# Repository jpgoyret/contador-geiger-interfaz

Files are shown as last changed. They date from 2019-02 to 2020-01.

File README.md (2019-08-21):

# Interfaz de manejo y visualización de los datos de un contador Geiger-Müller en microcontrolador de 8 bits

## Descripcion:
Dispositivo para controlar y recibir información de un detector de partículas radioactivas. Este informa la cantidad de partículas que han sido recibidas en un intervalo de tiempo deseado y, en particular, comunica cuando se ha superado un umbral de radiación establecido por el usuario.

El primer prototipo funcional de este proyecto fue realizado en el marco de la materia "6609/8607 Laboratorio de Microcontroladores" en la Facultad de Ingeniería de la Universidad de Buenos Aires (FIUBA).

La intrerfaz fue desarrollada sobre un microcontrolador de 8 bits Atmega328p (integrado en un Arduino) y programada en Assembly.

## Navegación del repositorio

En el archivo [Documentacion_Contador_Geiger](Documentacion_Contador_Geiger.pdf) se podrá encontrar la documentación propia de la interfaz incluyendo: breve descripción del desarrollo, diagramas de flujo y de bloques, componentes de la interfaz, conexiones, entre otros.

En [Mediciones_Contador_Geiger](Mediciones_Contador_Geiger.pdf) se incluyen las mediciones realizadas sobre el contador Geiger por medio de la interfaz de manejo y visualización de datos. Para dichas pruebas se empleó una fuente elevadora de tensión elaborada por Ing. Ricardo Arias.

#### Carpetas:

- Codigo: incluye el código fuente del programa que irá embebido en el microcontrolador Atmega328p. Dicho código puede ser copiado y pegado dentro de la carpeta de un proyecto de Atmel Studio para poder ser modificado.
- diseño_caja_contador_geiger: contiene los archivos 3D del diseño de una caja que contenga a la fuente elevadora de tensión armada en una placa de 10cmx10cm.
- esquematicos: contiene los esquemáticos del PCB del shield del Arduino y del teclado.

## Integrantes del equipo:
- Nuñez Frau, Federico
- Vidal, Gabriel
- Goyret, Juan Pablo

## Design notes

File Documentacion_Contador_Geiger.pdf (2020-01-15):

## Interfaz de manejo y visualización de los datos de un contador Geiger-Müller

## Documentación

Facultad de Ingeniería, Universidad de Buenos Aires

15 de enero de 2020

## Autores:

Nuñez Frau, Federico | 98211 | fedenunez32@gmail.com
Vidal, Gabriel | 97772 | vidalgabriel93@gmail.com
Goyret, Juan Pablo | 99081 | juanpablogoyret@gmail.com

Índice

1. Descripción | 2
2. Diagrama de bloques | 3
3. Diagramas de flujo | 4
4. Esquemático | 5
5. Configuración de la interfaz | 6
6. Comunicación | 7
7. Firmware | 11

### 1. Descripción

El dispositivo consiste en una interfaz de manejo y visualización de los datos de un contador Geiger-Müller, el cual es un circuito analógico generador de pulsos de tensión a partir de las partículas radioactivas que son recibidas en un tubo Geiger- Müller. Este último es un tubo de vidrio entre cuyos bornes se debe crear una tensión en torno a los cientos de volts y que, al recibir una partícula radioactiva, genera un pulso de corriente entre su ánodo y su cátodo, el cual es luego transformado a un pulso de tensión por un circuito secundario. Dado que las partículas arriban al tubo en instantes de tiempo aleatorios, los pulsos también se generan de este modo.
Estos pulsos de tensión son contados por un microcontrolador Atmega328p embebido en una placa Arduino, el cual realiza la tarea de determinar cuantos de estos han sido detectados en una unidad de tiempo dada, al igual que registrar los tiempos de llegada de cada pulso, para luego informarlo al usuario. Como se observa en el diagrama de bloques de la Figura 1, los pulsos de tensión son comunicados al microcontrolador a través de opto-acopladores rápidos, para aislar eléctricamente al circuito analógico del digital (además, ambos se encuentran en placas separadas). Se cuenta además con una salida del microcontrolador opto-acoplada para encender la fuente de alta tensión que excita el tubo Geiger-Müller. El microcontrolador informa la cantidad de pulsos de tensión recibidos por unidad de tiempo al usuario por medio de un panel LCD 2x16; así como también a una PC por medio de USB, empleando el sistema de comunicación UART y utilizando el protocolo SCPI (Standard Commands for Programmable Instruments)

1
. Este último medio es también utilizado para enviar los tiempos de llegada de cada pulso, permitiéndole al usuario realizar, por ejemplo (pero no contemplados en este trabajo), análisis estadísticos de la radiación recibida. Esta conexión permite, además, dar comienzo o detener mediciones a través de la PC.
Además, el sistema cuenta con un teclado conformado por 6 pulsadores: flechas en las 4 direcciones, un botón de cancelar y uno de aceptar; con las siguientes funciones:

Controlar el largo del intervalo de tiempo en el cual se cuentan los pulsos antes de informar un valor al usuario o "ventana de tiempo". Este valor se modifica mediante un menú de configuración visible en el display LCD.

Dar comienzo o detener las mediciones.

Configurar un umbral de pulsos recibidos por unidad de tiempo, el cual, de ser superado, implica el encendido de un LED rojo (de no ser superado el umbral se mantiene encendido un LED verde) y/o la activación de una alarma.

El microcontrolador utilizado se encuentra embebido en una placa Arduino UNO Rev3. Sobre este se acopla mediante pines largos una placa aparte (utilizando el formato poncho o shield), el cual contiene el buzzer para la alarma sonora y conectores para tres cables dirigidos a 3 placas extra. Una de ellas posee el display LCD; otra el teclado y los LEDs; y la última la fuente elevadora de tensión del contador. Por otro lado, la otra placa cuenta con la fuente de alta tensión encargada de alimentar al tubo del contador, y comunicar los pulsos al Atmega328.
El circuito analógico será alimentado mediante un transformador de 220V a 6V, contando el bloque digital con una alimentación independiente.
En las Figuras 2 y 3 se muestran los diagramas de flujo del menú de control y del sistema contador de pulsos respectivamente.

1
“SCPI 1999.0".Internet: http://www.ivifoundation.org/docs/scpi-99.pdf [Mayo, 1999]

### 2. Diagrama de bloques

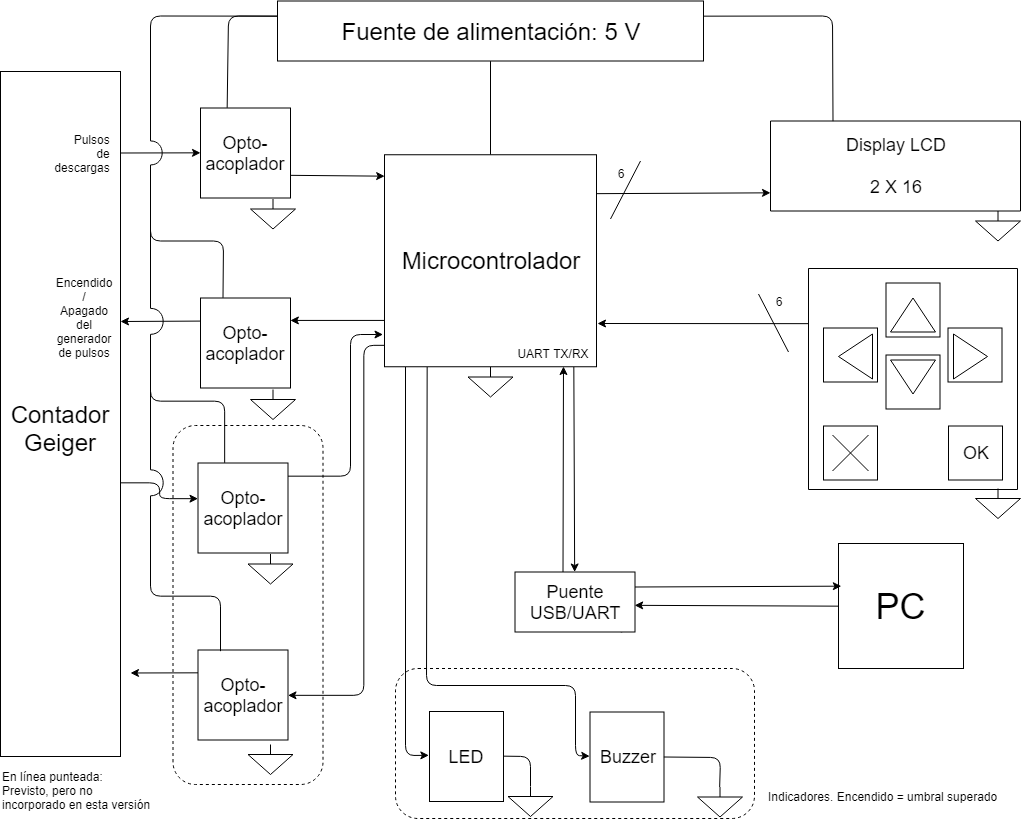
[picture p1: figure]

Figura 1: Diagrama de bloques.

### 3. Diagramas de flujo

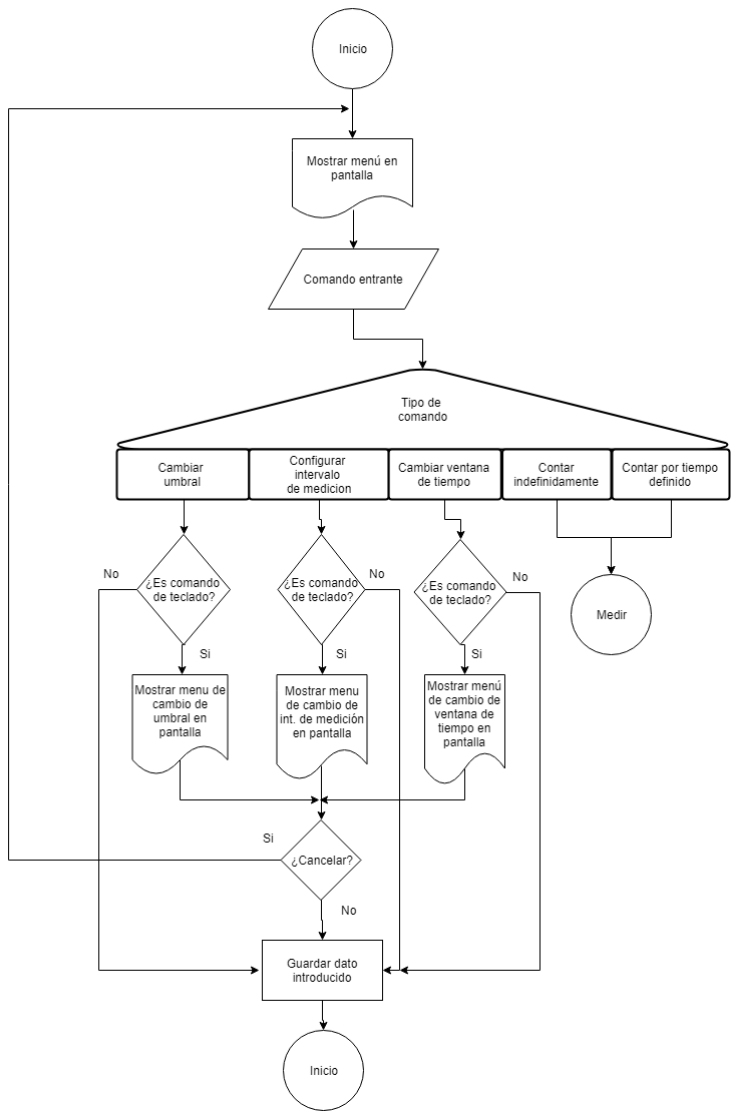
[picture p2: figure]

Figura 2: Diagrama de flujo del menú de control del contador.

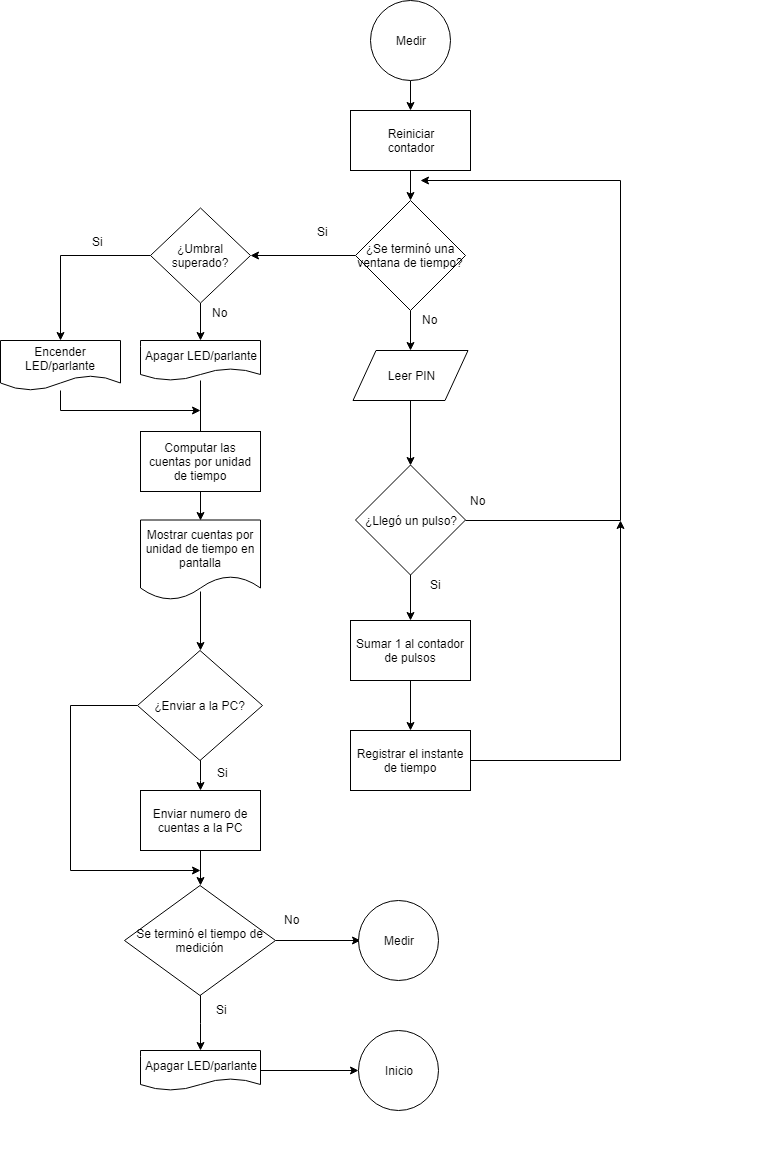
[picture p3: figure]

Figura 3: Diagrama de flujo del algoritmo de medición.

### 4. Esquemático

Los esquemáticos se podrán ver accediendo a los distintos proyectos en Kicad dentro del repositorio del proyecto en la carpeta proyectos_esquematico_kicad. A continuación se listan los nombres de cada proyecto con el correspondiente componente que representan de todo el dispositivo:

Placa_lcd_cont_geiger: shield de Arduino del cual parten los conectores que se dirigen a la placa del teclado y a la placa que posee la fuente elevadora.

esquematico_lcd: placa adaptadora que solamente cuenta con un puerto IDC para recibir las señales del Arduino y dirigirlas a los pines de la pantalla LCD.

teclado_contador_geiger: placa con el teclado para comandar el dispositivo y los LEDs rojo y verde indicadores.

### 4.1. Pines del microcontrolador/Arduino y su función

A continuación, en el Cuadro 1 se especifica la funcionalidad de cada pin del microcontrolador Atmega328p para el contador Geiger, junto con su correlación con las salidas del Arduino UNO R3.

Pin Arduino UNO R3 | Pin Atmega328p | Funcionalidad
Digital 0 | PD0 | Comunicación UART - RX
Digital 1 | PD1 | Comunicación UART - TX
Digital 2 | PD2 | Pantalla LCD: RS
Digital 3 | PD3 | Pantalla LCD: E
Digital 4 | PD4 | Pantalla LCD: datos
Digital 5 | PD5 | Pantalla LCD: datos
Digital 6 | PD6 | Pantalla LCD: datos
Digital 7 | PD7 | Pantalla LCD: datos
Digital 8 | PB0/ICP1 | Recepción de pulsos del tubo
Digital 12 | PB4 | Habilitación de la fuente de alta tensión
Analógico 0 (A0) | PC0 | Teclados
Analógico 1 (A2) | PC1 | Encendido de buzzer indicador
Analógico 4 (A4) | PC4 | Encendido del LED indicador verde
Analógico 5 (A5) | PC5 | Encendido del LED indicador rojo

Cuadro 1: Listado de los pines del Arduino UNO R3/Atmega328p con su respectiva funcionalidad para el contador Geiger.

### 5. Configuración de la interfaz

### 5.1. Parámetros configurables

La interfaz de control y gestión contempla la posibilidad de configurar los siguiente parámetros de medición:

Cantidad de ventanas de tiempo a medir: entre 1 y 99999.

Duración de las ventanas de tiempo a medir: 1ms, 10ms, 100ms o 1s.

Umbral por encima del cual se activa una señal luminosa o sonora: entre 0 y 99999.

Activación o desactivación de la señal sonora.

Activación o desactivación de la fuente de alta tensión del tubo del contador Geiger-Müller.

Activación del modo para retornar los tiempos de llegada de las partículas radioactivas al tubo.

A su vez, también es posible guardar las configuración del dispositivo en memoria EEPROM (mediante el comando *SAV por UART). De hacerselo, al resetearse este tomará automáticamente la configuración guardada.

### 5.2. Configuración por default

Los siguientes valores son los correspondientes a la configuración por default del dispositivo.

Tiempo de la ventana: 1s.

Número de ventanas: 10.

Umbral de la señal luminosa/sonora: 1.

Estado de la fuente: desactivada.

Envío de tiempo de llegada de cada pulso: desactivado.

El dispositivo puede ser retornado a su configuración por default ejecutando el comando *RST.

### 6. Comunicación

### 6.1. Comunicación con PC / serie

La comunicación serie por USB con la PC se realiza empleado la USART del Atmega328p en modo UART. Para la conexión física se utiliza el harware del propio Arduino como adaptador de serie a USB. La comunicación por UART se encuentra configurada del siguiente modo:

Baud rate: 76800 (se genera un 2 % de error).

Tamaño de la palabra: 8 bits.

Bit de paridad: no.

Cántidad bits de stop: 1

Las cadenas de texto con comandos SCPI a enviar deben terminar con el caracter de retorno de carro ˚. Por ejemplo, para comenzar una lectura enviar: READ?˚. De otro modo, el dispositivo nunca identificará que el mensaje enviado ha terminado y lanzará un error por timeout, devolviendo por consola el código -365.
Para comunicarse desde una PC puede utilizarse, por ejemplo, el programa PuTTY (al momento de realizar este trabajo, su última versión es la 0.7) disponible para Windows y Unix. Además de configurar el baud rate, el tamaño de palabra, el bit de paridad y el número de bits de stop como ya fue indicado, se debe configurar la pestaña "terminal"del modo en el que se muestra en la Figura 4

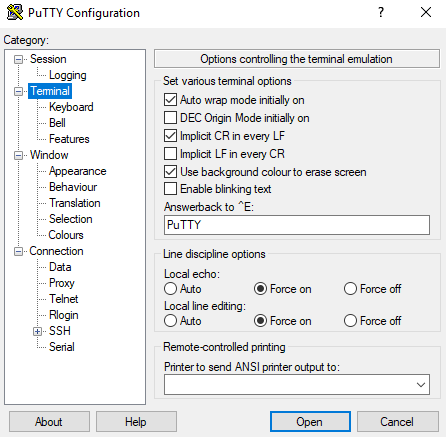
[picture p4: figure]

Figura 4: Configuración de la pestaña terminal de PuTTY.

### 6.2. Protocolo SCPI

Como ya se indicó, la comunicación serie se realiza utilizando el protocolo SCPI. Los comandos implementados son los que se muestras en el Cuadro 2.

Comando | Parámetro | Acción
*IDN? | N/C | Devolver un mensaje de identificación del dispositivo
*RST | N/C | Devolver la configuración del dispositivo a sus valores por default (ver 5.2)
READ? | N/C | Iniciar una medición utilizando la configuración actual del dispositivo
ABORt | N/C | Detener una medición
CONFigure? | N/C | Devolver la configuración de todo el dispositivo
CONFigure:WINDow <N> | Tamaño de la ventana. Valores posibles de N: 0 (1ms), 1 (10ms), 2 (100ms) y 3 (1s) | Configurar la duración de las ventanas de tiempo
CONFigure:WINDow? | N/C | Devolver el tamaño de la ventana de tiempo
CONFigure:COUNt <N> | Entre 1 y 99999 | Configurar la cantidad de ventanas a medir
CONFigure:COUNt 0 | N/C | Medir infinitas ventanas
CONFigure:COUNt? | N/C | Devolver el número de ventanas a medir
CONFigure:TRIGger <N> | Entre 0 y 99999 | Configurar el valor del umbral a partir del cual se enciende el LED o la alarma sonora (de encontrarse activada)
CONFigure:TRIGger? | N/C | Devolver el valor del umbral
CONFigure:DATA <BOOL> | 0 (desactivado) o 1 (activado) | Configurar el retorno de los tiempos de los pulsos que arribar al contador
CONFigure:DATA? | N/C | Devolver si el el retorno de los tiempos de los pulsos está activado o no
CONTrol:APOWer <BOOL> | 0 (desactivado) o 1 (activado) | Encender o apagar la fuente de alta tensión
CONTrol:APOWer? | N/C | Devolver si el tubo se encuentra recibiendo alta tensión o no
SYSTem:BEEPer:STATe <BOOL> | 0 (desactivado) o 1 (activado) | Encender o apagar la alarma sonora
SYSTem:BEEPer:STATe? | N/C | Devolver si la alarma sonora se encuentra activada
*SAV | N/C | Guardar la configuración del dispositivo en memoria EEPROM para retomarla cuando este se reinicie

Cuadro 2: Comandos SCPI implementados para comunicación serie. <N>es un parámetro representado por un número entero, mientras que <BOOL>uno representado por un booleano.

Varios comandos mostrados en el Cuadro 2 tienen una forma extendida y una forma reducida. La forma extendida comprende todos los caracteres del comando tal y como se lo muestra en la columna izquierda de la tabla. Por otro lado, la forma reducida se ve representada solamente por la letras en mayúscula y los símbolos como ": ²

¿". Tanto la forma reducida como la extendida son válidas. Por ejemplo, si se tiene el comando ÇONFigure:DATA?", su forma reducida sería ÇONF:DATA?". Del mismo modo, con CONFigure:WINDow <N>, su forma reducida es CONF:WIND <N>. En ambos casos ejemplo se obtendrá la misma respuesta tanto para el comando extendido como para el reducido.
A continuación se muestran algunos ejemplos. Recordar que a todos los comandos, tal y como son presentados en dichos ejemplos, se les debe agregar el caracter de retorno de carro (˚) de modos que sean correctamente interpretados por la interfaz.

### 6.2.1. Ejemplo 1

Suponiendo que se quisiera encender la alimentación de alta tensión del tubo del contador Geiger, se podría ejecutar el siguiente comando:

CONTrol:APOWer 1

O, en su forma, reducida:

CONT:APOW 1

Y también se podría enviar, por ejemplo:

CONT:APOWer 1

o bien,

CONTrol:APOW 1

En todos los casos, la fuente de alta tensión será encendida.

### 6.2.2. Ejemplo 2

Si se quisiera configurar la ventana de tiempo en 10ms y que el dispositivo mida 100 ventanas se podrían enviar los siguientes comandos:

CONF:WIND 2
CONF:COUN 100

### 6.2.3. Ejemplo 3

Si se quisiera saber el número de pulsos recibidos en la ventana de tiempo configurada tal que la señal luminosa o sonora se encienda (umbral superado), se podría ejecutar el siquiente comando:

CONF:TRIG?

Y el dispositivo devolverá el valor correspondiente

### 6.2.4. Códigos

La implementación del protocolo SCPI en la interfaz de gestión y control contempla algunos códigos de error o de información, que son los que se presentan en el Cuadro 3

Código | Significado
-100 | El comando recibido es erróneo
-365 | Timeout en la recepción de un comando. Se ha comenzado a recibir un comando pero su último caracter ha tardado demasiado tiempo en llegar.
-363 | Comando demasiado extenso (>60 caracteres). Overflow en el buffer de recepción de comandos
-284 | Dispositivo ocupado. No se puede recibir un comando en este momento

Cuadro 3: Códigos implementados del estándar SCPI.

### 7. Firmware

### 7.1. Máquinas de estado y eventos

El firmware consiste principalmente de 3 máquinas de estado, cada una asociada a funcionalidades distintas de la interfaz de control y gestión. Estas son:

Realización de las mediciones.

Recepción y envío de datos por UART.

Menú mostrado en la pantalla LCD del dispositivo.

Los estados de las primeras dos máquinas se encuentran almacenados en el registro ESTADO (R24), mientras que el de la tercera lo hace en ESTADOS_LCD (R22). Ambos son registros reservados que no pueden ser accedidos por ningún otro proceso.
Las máquinas cambian de estado o ejecutan acciones dependiendo de los eventos que ocurran en el microcontrolador, como la llegada de un caracter por UART o un pulso por el pin ICP1. Dichos estados se almacenan en el registro reservado EVENTO (R25), y en el registro en RAM EVENTO2. Este último fue creado debido a la falta de registros de acceso común disponibles para ser reservados a una tarea en específico.

### 7.2. Timers

La interfaz de control y gestión utiliza los tres timers disponibles en el microcontrolador Atmega328P. Sus funciones son:

Timer 0:

- Identificar un timeout (o exceso de tiempo) en la recepcion de una cadena de caracteres por UART. Se genera una interrupcion si ha transcurrido un cierto tiempo desde la llegada de un primer caracter sin que se haya recibido un caracter de fin de trama.
- Debouncer para detectar la pulsación de una tecla en el teclado mediante el comparador y el ADC.

Timer 1: guardar los instantes de tiempo de los pulsos capturados.

Timer 2: generar los delays del LCD.

### 7.3. Registros

En el Cuadro 4 pueden verse los registros de uso común R0 a R31 catalogados según su uso. Si se encuentran reservados para alguna tarea en específico (no pueden ser utilizados en ninguna otra función que no sean aquellas relacionadas con el proceso para el cual se encuentran justamente reservados), entonces se aclara su motivo.

Registro | Reservado | Uso | Definición
R0 | Si | Multiplicaciones | N/C
R1 | Si | Multiplicaciones | N/C
R2 | Si | Contador del timer 0 | CONT_TIMER0_LOW
R3 | Si | Contador del timer 0 | CONT_TIMER0_HIGH
R4 | No | Uso general | N/C
R5 | No | Uso general | N/C
R6 | No | Uso general | N/C
R7 | No | Uso general | N/C
R8 | Si | Puntero al LSB del buffer de transmisión de UART | PTR_TX_L
R9 | Si | Puntero al MSB del buffer de transmisión de UART | PTR_TX_H
R10 | Si | Puntero al LSB del buffer de recepción de UART | PTR_RX_L
R11 | Si | Puntero al MSB del buffer de recepción de UART | PTR_RX_H
R12 | Si | Cantidad de caracteres almacenados en el buffer de transmisión de datos de UART | BYTES_TRANSMITIR
R13 | Si | Cantidad de caracteres almacenados en el buffer de recepción de datos de UART | BYTES_RECIBIDOS
R14 | No | Uso general | N/C
R15 | Si | Multiplicador para extender el tamaño de la ventana de tiempo | MUL_DE_VENTANA
R16 | No | Uso general | N/C
R17 | No | Uso general | N/C
R18 | No | Uso general | N/C
R19 | No | Uso general | N/C
R20 | No | Uso general | N/C
R21 | No | Uso general | N/C
R22 | Si | Estados de la máquina de estados del LCD | ESTADOS_LCD
R23 | Si | Lleva la cuenta de la cantidad de pulsos medidos | CONTADOR_DE_PULSOS
R24 | Si | Almacenamiento de los estados de las máquinas de estado de la comunicación serie y del sistema de recepción de los pulsos | ESTADO
R25 | | Almacenamiento de eventos que alteran los estados de las máquinas de estado | EVENTO
R26 | Si | Puntero X | N/C
R27 | Si | Puntero X | N/C
R28 | Si | Puntero Y | N/C
R29 | Si | Puntero Y | N/C
R30 | Si | Puntero Z | N/C
R31 | Si | Puntero Z | N/C

Cuadro 4: Comandos SCPI implementados para comunicación serie. <N>es un parámetro representado por un número entero, mientras que <BOOL>uno representado por un booleano. En la última columna se aclara la definición del registro en el código si es que se lo ha redeclarado con ".def".

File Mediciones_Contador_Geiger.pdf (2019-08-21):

## Interfaz de manejo y visualización de los datos de un contador Geiger-Müller

## Mediciones

Facultad de Ingeniería, Universidad de Buenos Aires

## Autores:

Nuñez Frau, Federico | 98211 | fedenunez32@gmail.com
Vidal, Gabriel | 97772 | vidalgabriel93@gmail.com
Goyret, Juan Pablo | 99081 | juanpablogoyret@gmail.com

Índice

1. Diciembre 2018 | 2
2. Febrero 2019 | 2
2.2. Datos reportados por el contador Geiger en la consola serie del Atmel Studio 7 para las

### 1. Diciembre 2018

A continuación, en la Tabla 1 se muestran los resultados reportados por el contador por UART para distintas mediciones con el tubo colocado en la pared de la fuente de radiación. Se realizaron 12 mediciones de 10 segundos cada una. Cada dato se corresponde con la cantidad de pulsos detectados durante 1 segundo. Vale aclarar que estás mediciones fueron para un mismo tubo, que fue el tercero utilizado.
No se han incluido los resultados para mediciones con el tubo sin colocar en la pared de la fuente debido a que en ningún momento se detectaron pulsos para este caso.
Medición | t = 1 | t = 2 | t = 3 | t = 4 | t = 5 | t = 6 | t = 7 | t = 8 | t = 9 | t = 10
1ra | 00167 | 00177 | 00156 | 00170 | 00213 | 00096 | 00155 | 00208 | 00157 | 00106
2da | 00093 | 00146 | 00171 | 00155 | 00146 | 00075 | 00124 | 00075 | 00157 | 00093
3ra | 00135 | 00062 | 00081 | 00065 | 00151 | 00117 | 00149 | 00101 | 00118 | 00043
4ta | 00052 | 00077 | 00047 | 00039 | 00116 | 00080 | 00115 | 00127 | 00084 | 00073
5ta | 00084 | 00089 | 00082 | 00114 | 00103 | 00153 | 00077 | 00185 | 00111 | 00016
6ta | 00068 | 00106 | 00097 | 00098 | 00044 | 00093 | 00149 | 00121 | 00099 | 00176
7ta | 00105 | 00087 | 00117 | 00132 | 00117 | 00134 | 00056 | 00114 | 00127 | 00101
8va | 00106 | 00047 | 00135 | 00055 | 00069 | 00032 | 00043 | 00087 | 00055 | 00099
9na | 00254 | 00104 | 00084 | 00036 | 00078 | 00085 | 00107 | 00120 | 00082 | 00083
10ma | 00152 | 00243 | 00241 | 00023 | 00246 | 00188 | 00206 | 00037 | 00249 | 00206
11ra | 00200 | 00240 | 00186 | 00193 | 00047 | 00012 | 00226 | 00218 | 00228 | 00201
12da | 00176 | 00247 | 00197 | 00178 | 00250 | 00224 | 00209 | 00225 | 00170 | 00185

Cuadro 1: Cuentas por segundo obtenidas durante 10 segundos para 12 mediciones distintas con el tubo pegado a la pared de la fuente de radiación.

### 2. Febrero 2019

Fecha: 8/2/19

Tubo utilizado: SBM-20

Tensión aplicada en los bornes del tubo: 400V (la tensión de alimentación recomendada)

Resistencia en serie con el tubo: 1MOhm (integrada en la placa) + 5.6MOhm (fuera de placa; agregada al tubo) = 6.6 MOhm (la resistencia recomendada es 5MOhm).

Placa del tubo alimentada con una fuente de 12V DC.

Dispositivos utilizados:

Multímetro UNI-T UT33A.

Contador Geiger de mano Galert 500P.

Procedimiento: se realizaron mediciones para el contador Geiger de mano y el contador desarrollado en la materia. Para cada caso, las superficies receptoras de radiación de cada uno fueron apoyadas en la tapa de la cámara más cercana a la fuente de radiación (la parte trasera de dispositivo en el caso del Galert, y el tubo en el caso del contador desarrollado por cuenta propia). Se configuró al Galert para que midiera constantemente los pulsos por minuto detectados y cada 10 segundos se tomó una medición. Por otro lado, se programó al contador Geiger propio para medir ventanas de 1 segundo durante 10 segundos, y finalmente se anotó el promedio de pulsos por segundo recibidos al final de ese periodo de tiempo. Los procedimientos para ambos dispositivos fueron realizados con la fuente de radiación apuntando en el sentido de la tapa y sin hacerlo. Finalmente, se tomaron mediciones en vacío de ambos dispositivos, es decir, estando el tubo y el Galert apoyados sobre una mesa, alejados de la fuente de radiación.

### 2.1. Mediciones

### 2.1.1. Galert 500P

CPM: cuentas por minuto Con radiación: con la fuente apuntando en el sentido de la tapa

| Con radiación | Sin radiación | En vacío
Núm. de medición | CPM | CPM | CPM
1 | 5020 | 100 | 30
2 | 4620 | 200 | 90
3 | 4690 | 170 | 50
4 | 4500 | 200 | 20
5 | 4760 | 200 | 50
6 | 4330 | 250 | 40
7 | 4560 | 140 | 70
8 | 4310 | 140 | 70
9 | 4480 | 190 | 40
10 | 4710 | 220 | 50
11 | 4640 | 180 | 20
12 | 4410 | 140 | 40
13 | 4490 | 220 | 30
Media | 4578 | 181 | 46
Desviación estándar | 194 | 42 | 21

### 2.1.2. Contador Geiger propio

PCS: promedio de cuentas por segundo

| Con radiación | Sin radiación | En vacío
Núm. de medición | PCS | PCS | PCS
1 | 109 | 14 | 1
2 | 140 | 27 | 1
3 | 121 | 4 | 1
4 | 86 | 7 | 1
5 | 105 | 7 | 0
6 | 147 | 20 | 1
7 | 147 | 1 | 0
8 | 127 | 7 | 0
9 | 122 | 15 | 0
10 | 103 | 7 | 0
11 | 108 | 12 | 0
12 | 117 | 10 | 0
13 | 147 | 24 | 0
Media | 121 | 12 | 0.4
Desviación estándar | 19 | 8 | 0.5

Finalmente, para el caso en vacío, se realizaron mediciones con el contador propio usando una ventana de 100ms y realizando un promedio de los pulsos recibidos cada 1s (100 ventanas). En este caso, el promedio reportado fue 0 para todas las mediciones realizadas. Sin embargo, en algunas ventanas se pudo obtener una cantidad de pulsos detectados mayor a 0.

### 2.2. Datos reportados por el contador Geiger en la consola serie del Atmel Studio 7 para

las mediciones realizadas

Resultados del comando “CONF?”
Numero de ventanas:

00010
Duracion de la ventana:
1000
Umbral del trigger:
00020
Estado de la fuente: ON
Envio de tiempos de llegada de cada pulso: OFF Señal sonora: OFF
Bloqueo del teclado durante medicion: OFF

Mediciones sin fuente: cada línea representa la cantidad de pulsos recibidos por segundo. Cada medición de 10 segundos está separada por una línea “-800” (que indica la terminación de una operación en el estándar SCPI).

00032 00006 00000 00019 00000 00000 00011 00023 00033 00025 -800 00031 00032 00000 00095 00038 00034 00000 00036 00008 00000 -800 00000 00014 00000 00000 00000 00000 00000 00016 00010 00000 -800 00000 00000 00000 00020 00042 00000 00013 00000 00000 00000 -800 00000 00000 00025 00022 00000 00000 00007 00020 00000 00000 -800 00000 00000 00008 00041 00109 00013 00000 00000 00022 00012 -800 00006 00000 00000 00004 00000 00000 00000 00000 00000 00000 -800 00026 00014 00000 00000 00023 00000 00059 00024 00028 00000 -800 00000 00000 00042 00030 00000 00014 00000 00028 00043 00000 -800 00000 00000 00009 00000 00000 00000 00004 00042 00016 00007 -800 00000 00000 00019 00000 00004 00000 00032 00036 00030 00000 -800 00043 00000 00000 00000 00014 00000 00017 00000 00011 00024 -800 00051 00000 00000 00014 00042 00046 00024 00037 00000 00028 -800

Mediciones con fuente:

00027 00079 00143 00059 00020 00235 00167 00054 00158 00150 -800 00041 00249 00079 00223 00043 00192 00183 00182 00065 00149 -800 00208 00015 00215 00156 00031 00100 00228 00014 00034 00216 -800 00223 00164 00010 00002 00039 00165 00185 00006 00037 00129 -800 00096 00178 00018 00132 00010 00185 00045 00187 00200 00011 -800 00228 00170 00070 00195 00153 00193 00130 00037 00196 00107 -800 00170 00154 00194 00147 00022 00017 00104 00233 00204 00225 -800 00104 00075 00219 00012 00248 00062 00012 00133 00182 00225 -800 00222 00102 00046 00124 00010 00119 00015 00170 00253 00159 -800 00091 00106 00189 00117 00022 00227 00092 00043 00071 00078 -800 00183 00196 00170 00020 00123 00127 00002 00007 00138 00117 -800 00230 00036 00120 00002 00214 00190 00143 00143 00093 00005 -800 00226 00090 00235 00103 00100 00021 00170 00166 00244 00122 -800

Mediciones del video:
00010
Duracion de la ventana:
1000
Umbral del trigger:
00020
Estado de la fuente: ON
Envio de tiempos de llegada de cada pulso: OFF Señal sonora: OFF
Bloqueo del teclado durante medicion: OFF

00215 00216 00201 00149 00120 00219 00098 00241 00041 00009 -800 00068 00201 00173 00088 00203 00163 00012 00016 00151 00213 -800

Mediciones en vacío con ventana de 1s:
Numero de ventanas:
00010
Duracion de la ventana:
1000
Umbral del trigger:
00020

Estado de la fuente: ON
Envio de tiempos de llegada de cada pulso: OFF Señal sonora: OFF
Bloqueo del teclado durante medicion: OFF

00000 00000 00004 00000 00000 00000 00000 00000 00000 00007 -800 00000 00005 00000 00000 00000 00000 00007 00000 00000 00000 -800 00000 00010 00003 00000 00000 00000 00000 00000 00001 00000 -800 00000 00000 00000 00000 00000 00000 00000 00005 00007 00000 -800 00000 00000 00000 00000 00001 00000 00000 00000 00000 00000 -800 00000 00008 00000 00000 00000 00007 00000 00000 00000 00000 -800 00000 00000 00000 00000 00000 00000 00000 00000 00000 00000 -800 00000 00000 00000 00000 00000 00000 00000 00002 00000 00005 -800 00000 00002 00000 00000 00000 00000 00000 00000 00000 00000 -800 00000 00000 00000 00000 00000 00000 00000 00000 00000 00000 -800 00000 00000 00000 00000 00000 00000 00000 00006 00000 00000 -800 00000 00004 00000 00000 00000 00000 00000 00000 00000 00000 -800 00000 00005 00000 00000 00000 00000 00000 00000 00000 00000 -800

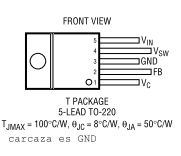
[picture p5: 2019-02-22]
proyectos_esquematico_kicad/esquematico_completo_primer_prototipo/LT1072.bmp

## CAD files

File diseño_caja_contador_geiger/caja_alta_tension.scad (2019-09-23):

// Carcasa para la placa de alta tensión

// Dimensiones que dan un resultado con sentido
//FootDia = 0.2;
//FootHole = 0.02;
//FootHeight = 0.2;
//Thick = 0.1;
//
//x = 3;
//y = 2;
//z = 1;
//dx = 0.4;
//dy = 0.4;
//dz = 0.4;
//rx = 0.1;
//ry = 1.8;
//rz = 0.1;

//DIMENSIONES DE LA PLACA
//9.4cm x 10.2 cm

//Dimensiones reales
//
FootDia = 8;    //Diametro del pie para la placa
FootHole = 0.1; //Agujero del tornillo
FootHeight = 14+2.6; //Altura del pie para la placa
Thick = 0.1;
Filet = 0.1;        //Constante que define el ancho de la base de los soportes para la placa

x = 114+2-5;
y = 115.3+2-4.44;
z = 70+2;
dx = 4+2;
dy = 4+2;
dz = 4+2;
rx = 1;
ry = 18;
rz = 1;

ex1 = 10;   //Espacio entre pared y placa del eje x en una dirección
ex2 = 3;    //Espacio entre pared y placa del eje x en la otra
ey1 = 3;    //Espacio entre pared y placa del eje y en una dirección
ey2 = 3.3;  //Espacio entre pared y placa del eje y en la otra

sx = 7;     //Espacio entre borde placa y pos. del agujero(+diametro)
sy = 5;    //Espacio entre el borde de la placa y la posicion del agujero (sumado el diametro)



// Posiciones de los soportes para la placa---------------
//pos_soportex1 = -x/2 + dx + ex2 + sx - FootDia/2;
//pos_soportex1 = -x/2 + dx - (FootDia+Filet)/2 + sx + ex2;
pos_soportex1 = -46.05+6-2.5;
pos_soportex3 = -46.05+6-2.5;
//pos_soportex2 = x/2 - dx - ex2 - sx + FootDia/2;
//pos_soportex2 = x/2 - dx + (FootDia+Filet)/2 - sx - ex1;
pos_soportex2 = 39.05+7-2.5;
pos_soportex4 = 39.05+7-2.5;
//pos_soportey1 = -y/2 + dy + ey1 + sy - FootDia/2;
//pos_soportey1 = -y/2 + dy+ ey1 + sy - (FootDia+Filet)/2;
pos_soportey1 = -48.7-5+2;
pos_soportey4 = -48.7-5+2;
//pos_soportey2 = y/2 - dy - ey2 - sy + FootDia/2;
//pos_soportey2 = y/2 - dy - ey2 - sy + (FootDia+Filet)/2;
pos_soportey2 = 48.4-6+2;
pos_soportey3 = 48.4-6+2;
pos_soportez = -(z-dz)/2;

//Agujero tubo---------------------------------------------------
//FUE CHEQUEADO
tubo_z = 16;
tubo_y = 8;
pos_tubo_x = x/2 - dx/4;
//pos_tubo_y = -y/2 + 45 - tubo_y/2;
pos_tubo_y = -y/2 -tubo_y/2 + 48;
//pos_tubo_z = -z/2 + 5 + 25 + tubo_z/2 + dz;
pos_tubo_z = -z/2 + tubo_z/2 + 30 - 10;
espesor_tubo = dx/2;

//Agujero Arduino-----------------------------------------------

arduino_x = 25;
arduino_z = 16;
pos_arduino_x = x/2 - arduino_x/2 - 33;
pos_arduino_y = -y/2 - dy/4;
pos_arduino_z = -z/2 + arduino_z/2 + 20 ;
espesor_arduino = dy/2;

//Agujero jack energía------------------------------------------

jack_x = 12;
jack_z = 14;
pos_jack_x = -x/2 + dx/4 + 33 + 4 - 2;
pos_jack_y = -y/2 - dy/4;
pos_jack_z = -z/2 + 23 + jack_z/2 - 4;
espesor_jack = dy/2;

//Ayuda para tornillo-------------------------------------------

tx = 10;
ty = 10;
tz = 35;
pos_tx = x/2-dx/2 - tx/2;
pos_ty = y/2-dy/2 - ty/2;
pos_tz = z/2 - tz/2;
d_tornillo = 2;

//Ayuda para tornillo tapa------------------------------------

//ttx = 70;
//tty = 12;
//ttz = 6;
ttx = 6;
tty = 30;
ttz = 30;
pos_ttx = -x/2 + ttx/2 + dx;
pos_tty = -y/2 + tty/2;
pos_ttz = -z/2 + ttz/2 + 30;

//Barras anti-flexibilidad--------------------------------------
off_z = 20;
off_x = 30;
bx = sqrt(pow(z-dz - off_z,2) + pow(y-dy,2)) - off_x;
by = dx/2;
bz = dx ;
pos_bx = x/2 - dx;
pos_by = y/2 - by/2 - dy/2;
pos_bz = z/2 - bz/4;
theta = atan((z-dz- off_z) / (y-dy));
alfa = atan((z-dz)/35);



module foot(FootDia,FootHole,FootHeight,Thick,Filet){
// Pie posa PCB
    // FootDia: diámetro de la parte donde se posa
    // FootHole: diámetro del agujero
    // FootHeigth: Altura del pie
    // Thick: cuanto se achica el pie para posar el PCB
    //Filet=2;  
    translate([0,0,0])
    difference(){
    
    difference(){
            //translate ([0,0,-Thick]){
                cylinder(d=FootDia+Filet,FootHeight-Thick, $fn=100);
                        //}
                    rotate_extrude($fn=100){
                            translate([(FootDia+Filet*2)/2,Filet,0]){
                                    minkowski(){
                                            square(10);
                                            circle(Filet, $fn=100);
                                        }
                                 }
                           }
                   }
            cylinder(d=FootHole,FootHeight+1, $fn=100);
               }          
}

module parte_inferior (x,y,z,dx,dy,dz,rx,ry,rz,tapa){
// Parte inferior de la placa de alta tensión
    
    // x: largo eje x
    // y: largo eje y
    // z: largo eje z
    // dx: grosor de la pared en el eje x
    // dy: grosor de la pared en el eje y
    // dz: grosor de la pared en el eje z
    // rx: largo del riel para encajar la tapa en el eje x
    // ry: largo del riel para encajar la tapa en el eje y
    // rz: largo del riel para encajar la tapa en el eje z
    //tapa: si vale 1 se genera la tapa, si vale 0, no
    
    difference(){
    
        cube([x,y,z],center=true);
        translate ([0,-dy/2,dz/2]) cube([x-dx,y,z],center=true);
//        translate ([x/2-dx/4,-(y-ry)/2,z/2-rz/2]) cube([rx,ry,rz],center=true);
//        translate ([-(x/2-dx/4),-(y-ry)/2,z/2-rz/2]) cube([rx,ry,rz],center=true);
//        translate ([-(x/2-dx/4),-(y-ry)/2,z/2-rz]) cube([rx*1.5,ry,rz],center=true);
//        translate ([x/2-dx/4,-(y-ry)/2,z/2-rz]) cube([rx*1.5,ry,rz],center=true);        
    }
}

module soporte_placa(x1,x2,x3,x4,y1,y2,y3,y4,z){
// Los cuatro pies donde se posa la placa

    translate ([x1,y1,z]) foot(FootDia,FootHole,FootHeight,Thick,Filet);
    translate ([x2,y2,z]) foot(FootDia,FootHole,FootHeight,Thick,Filet);
    translate ([x3,y3,z]) foot(FootDia,FootHole,FootHeight,Thick,Filet);
    translate ([x4,y4,z]) foot(FootDia,FootHole,FootHeight,Thick,Filet);  
    
    
}

//module tapa(x,y,z,dx,dy,dz,rx,ry,rz)
module tapa(x,y,z,dx,dy,dz)
{
    
    union(){
        translate ([0,-y/2-dy/4,0]) cube([x,dy/2,z],center=true);
        
        translate ([0,-dy/4,z/2+dz/4]) cube([x,y+dy/2,dz/2],center=true);
        
//        translate ([x/2-dx/4,-(y-ry)/2,z/2-rz]) cube([rx*1.5,ry,rz],center=true);
//        translate ([x/2-dx/4,-(y-ry)/2,z/2-rz/2]) cube([rx,ry,rz],center=true);
//        
//        translate ([-(x/2-dx/4),-(y-ry)/2,z/2-rz/2]) cube([rx,ry,rz],center=true);
//        translate ([-(x/2-dx/4),-(y-ry)/2,z/2-rz]) cube([rx*1.5,ry,rz],center=true);
        
        
        
    }
}

module agujero(dim_x,dim_y,dim_z,pos_x,pos_y,pos_z){
    
    translate ([pos_x,pos_y,pos_z]) cube([dim_x,dim_y,dim_z],center = true);    
}

module ayuda_para_tornillo(tx,ty,tz,pos_tx,pos_ty,pos_tz)
{
    translate([pos_tx,pos_ty,pos_tz]) cube([tx,ty,tz],center = true);
    
    translate([-pos_tx,pos_ty,pos_tz]) cube([tx,ty,tz],center = true);
    
    
    
//    difference(){
//        translate ([pos_tx,pos_ty,pos_tz]) cube([tx,ty,tz],center = true);
//        translate([pos_tx-(abs(pos_tx)/pos_tx)*tx/2,pos_ty-(abs(pos_tx)/pos_tx)*ty/2,pos_tz-tz/2]) rotate (a = [(abs(pos_tx)/pos_tx)*(-1)*90,-90,0]) linear_extrude(tx) polygon([[0,0],[tz,0],[0,ty]], paths=[[0,1,2]]);
//        translate([pos_tx+(abs(pos_tx)/pos_tx)*tx/4,pos_ty+ty/8,pos_tz + tz/2]) cylinder(h = tz/2 ,d = d_tornillo, $fn = 100,center = true);
//        
//        
//    }
}



module barras_anti_flex(bx,by,bz,theta)
{
    rotate (a = [0,theta,0]) cube ([bx,by,bz], center = true);
}

module placa()
{
    cube([94,102,2],center=true);
}

////////////////////// GENERACION DE LA PIEZA ////////////////////

////======================CAJA==========================\\
//
////rotate (a = [0,90,0]) 
//difference(){
//
module caja(){
union(){
difference(){
    parte_inferior (x,y,z,dx,dy,dz,rx,ry,rz);
    //Agujero del tubo
    agujero(espesor_tubo*2,tubo_y,tubo_z,pos_tubo_x,pos_tubo_y,pos_tubo_z);
    
}
//Soporte placa
soporte_placa (pos_soportex1,pos_soportex2,pos_soportex3,pos_soportex4,pos_soportey1,pos_soportey2,pos_soportey3,pos_soportey4,pos_soportez);

//Ayuda para tornillo
ayuda_para_tornillo(tx,ty,tz,pos_tx,pos_ty,pos_tz);
ayuda_para_tornillo(tx,ty,tz,-pos_tx,pos_ty,pos_tz);
//ayuda_para_tornillo(ty,tx,tz,-pos_tx+tx,pos_ty+tx,pos_tz);
//ayuda_para_tornillo(ty,tx,tz,+pos_tx-tx,pos_ty+tx,pos_tz);
////Ayuda para flexibilidad de caja
//translate ([0,pos_by,5]) barras_anti_flex(bx,by,bz,theta);
//
//translate ([0,pos_by,5]) barras_anti_flex(bx,by,bz,-theta);
//
//translate([-pos_bx,0,5]) rotate (a =[0,0,90]) barras_anti_flex(bx,by,bz,theta);
//
//translate([-pos_bx,0,5]) rotate (a =[0,0,90]) barras_anti_flex(bx,by,bz,-theta);
//
//translate([pos_bx,0,5]) rotate (a =[0,0,90]) barras_anti_flex(bx,by,bz,-theta);
//translate([pos_bx,-y/4,5]) rotate (a =[0,0,-90]) barras_anti_flex(bx-35,by,bz,-alfa);
//translate([pos_bx,y/6,5]) rotate (a =[0,0,-90]) barras_anti_flex(bx-35,by,bz,-alfa);


}
    //translate([-ex1,0,0]) cube([x,y,z],center=true);
//}
//translate ([0,0,z/3]) cube([x,y,z],center = true);


//}
}
module placa(){
%translate ([0,0,-z/2 + dz + pos_tubo_z+tubo_z]) placa();
}


//======================TAPA==========================\\
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

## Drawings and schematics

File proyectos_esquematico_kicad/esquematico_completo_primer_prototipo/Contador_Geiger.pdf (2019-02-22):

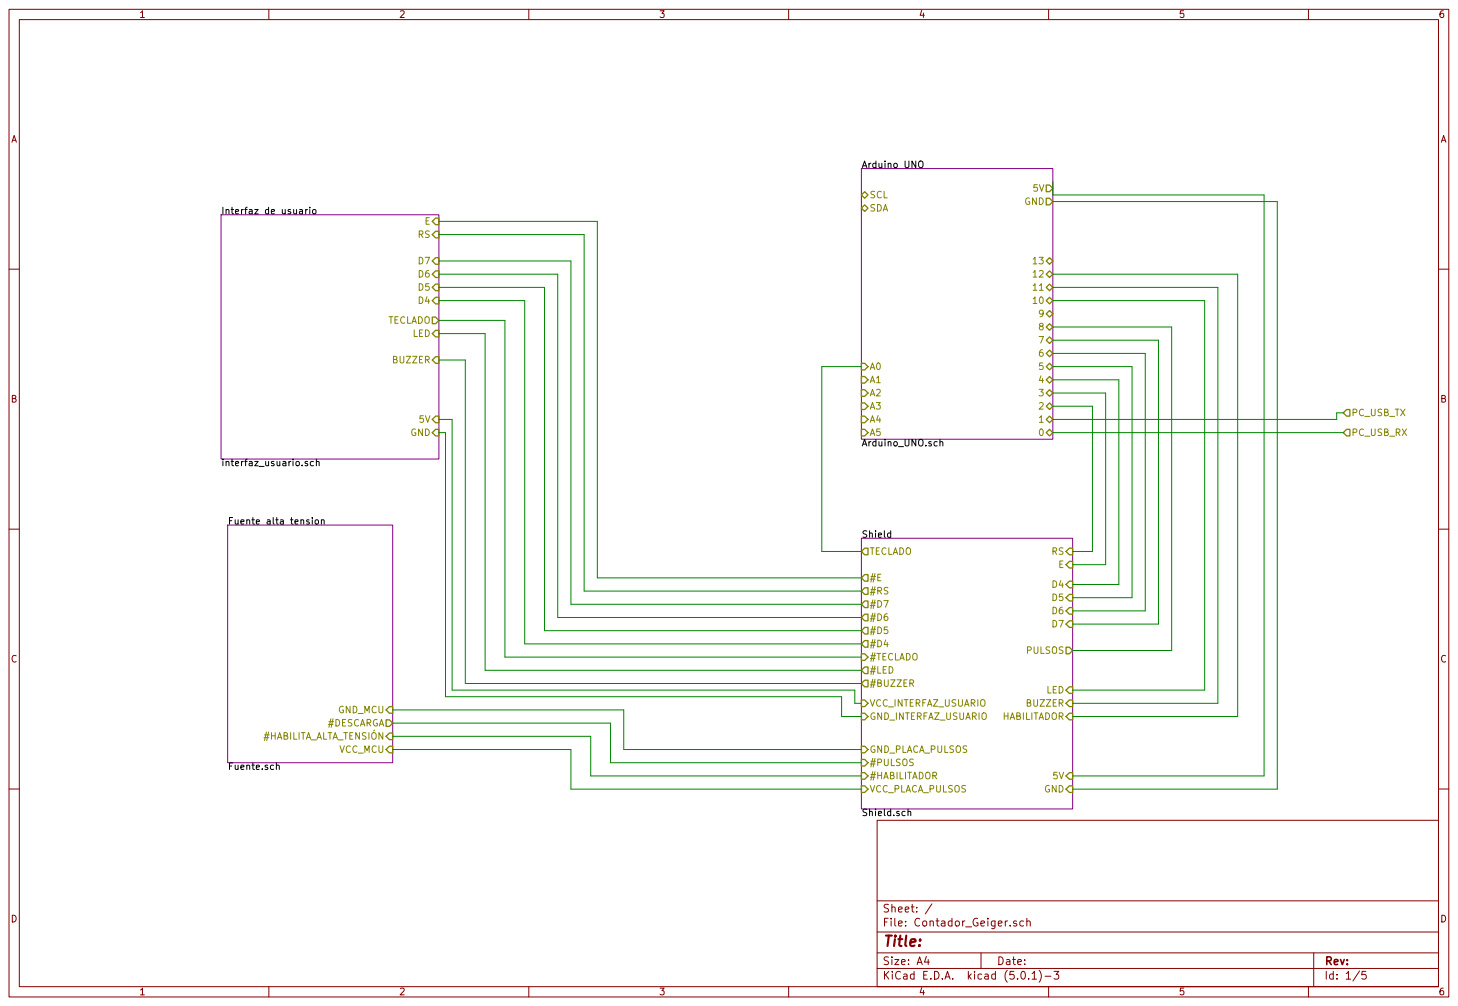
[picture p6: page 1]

5V GND
Fuente alta tension Fuente.sch

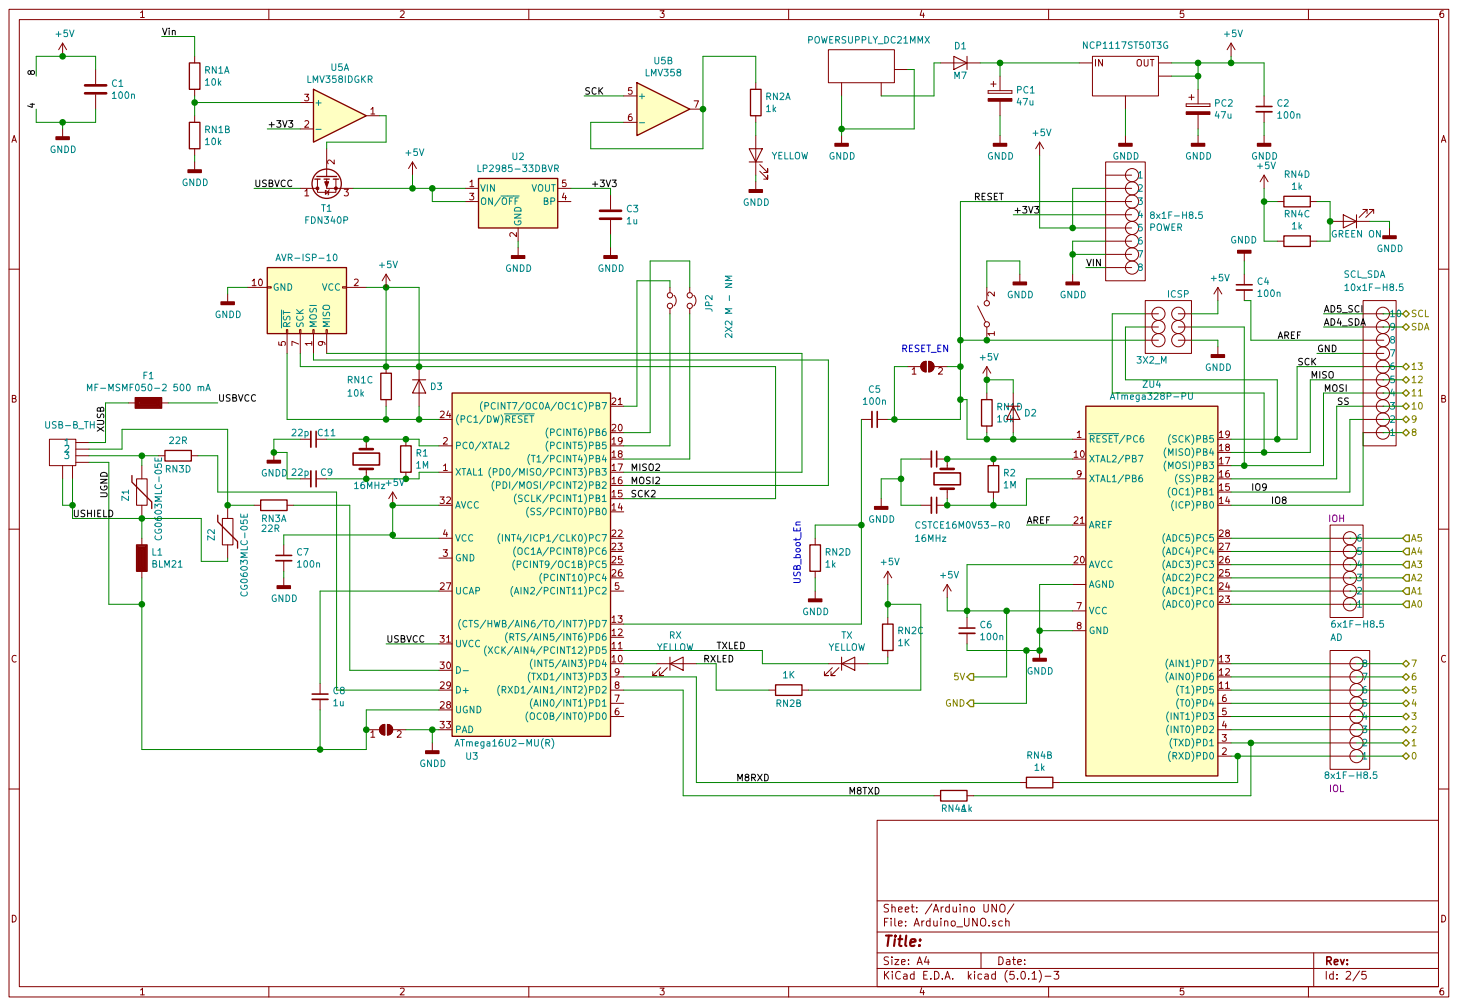
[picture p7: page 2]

2 ON/OFF 3 BP 4 VOUT 5 U2
LP2985-33DBVR

File: Arduino_UNO.sch Sheet: /Arduino UNO/
Id: 2/5 Title:

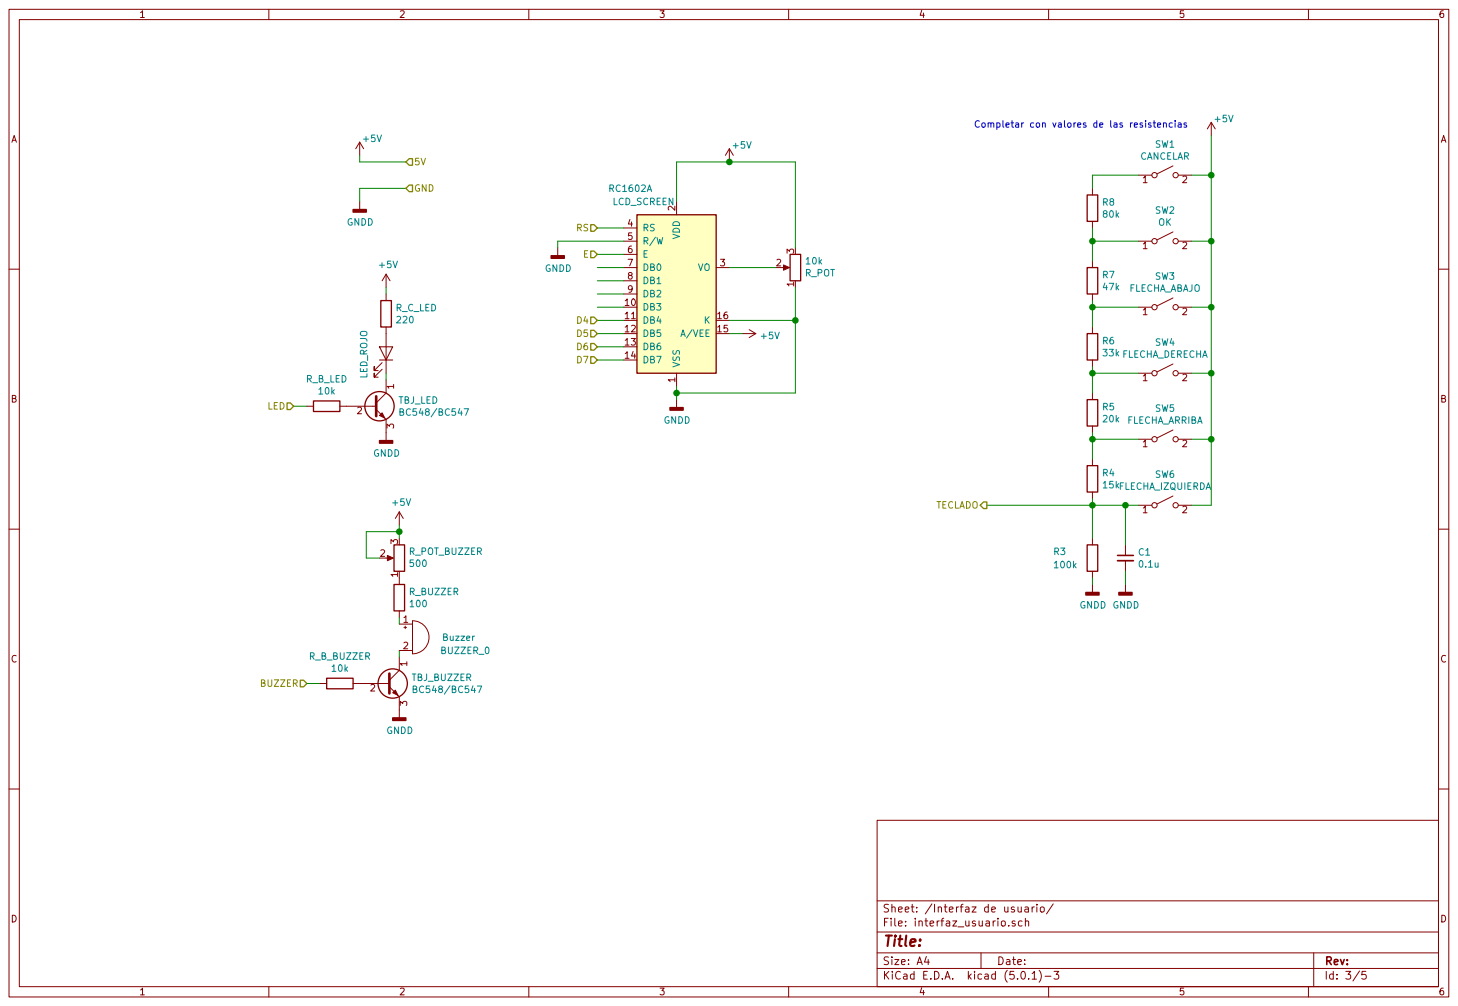
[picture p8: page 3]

Completar con valores de las resistencias

File: interfaz_usuario.sch Sheet: /Interfaz de usuario/ VSS

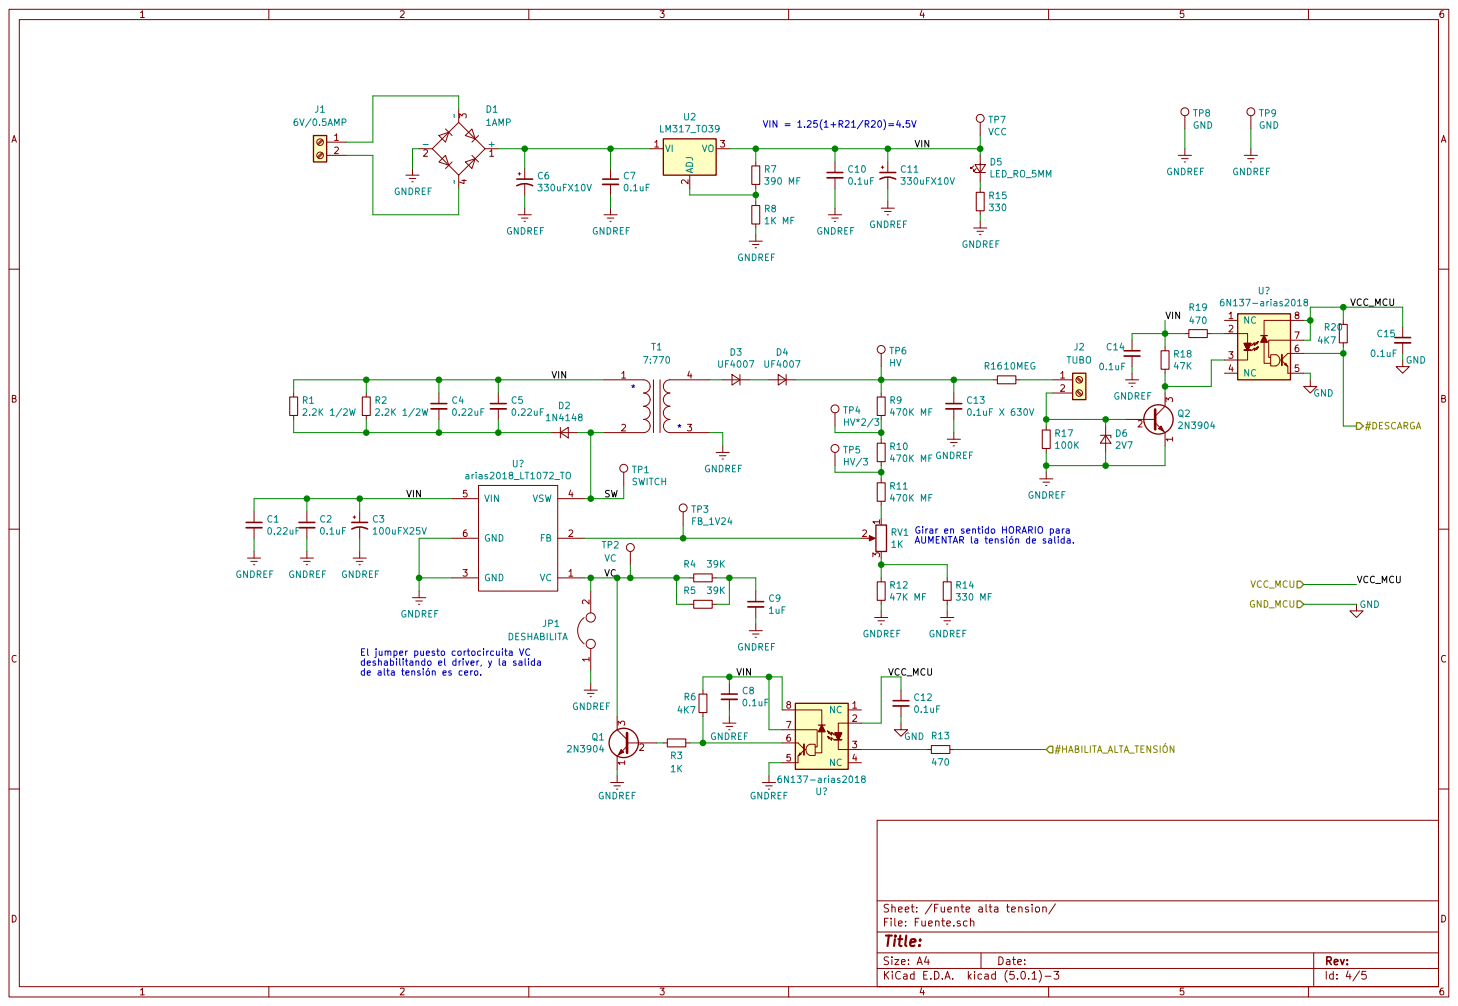
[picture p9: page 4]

Girar en sentido HORARIO para AUMENTAR la tensión de salida. C8

JP1 DESHABILITA GNDREF El jumper puesto cortocircuita VC

deshabilitando el driver, y la salida
de alta tensión es cero.

Id: 4/5 Title: File: Fuente.sch Sheet: /Fuente alta tension/

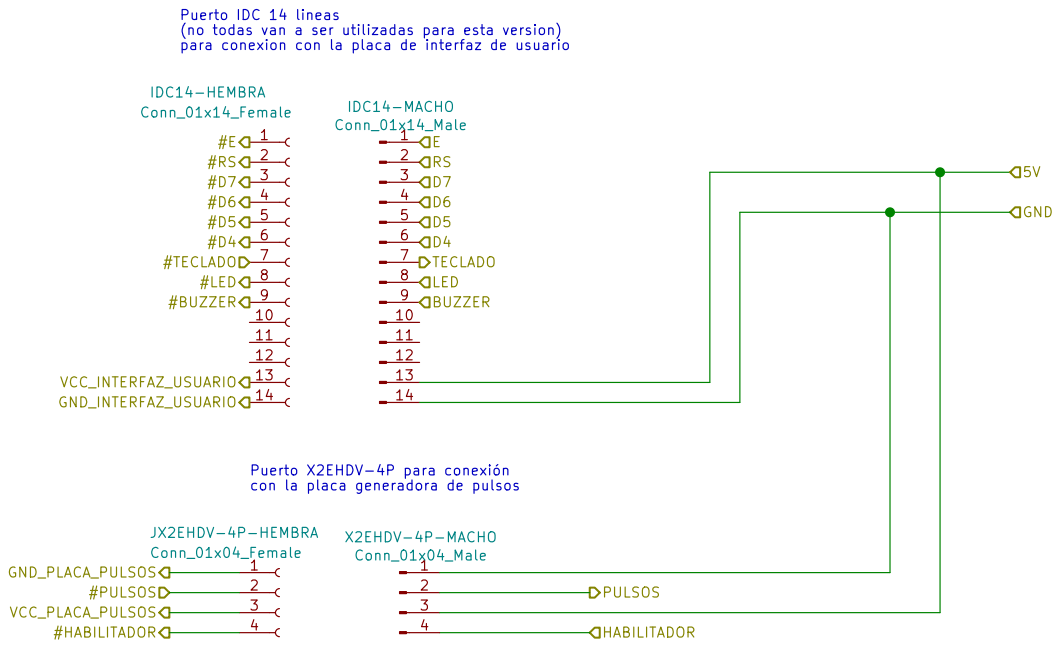
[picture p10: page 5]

Conn_01x14_Male Puerto IDC 14 lineas (no todas van a ser utilizadas para esta version)
para conexion con la placa de interfaz de usuario

Puerto X2EHDV-4P para conexión
con la placa generadora de pulsos 1

Id: 5/5 Title: File: Shield.sch Sheet: /Shield/

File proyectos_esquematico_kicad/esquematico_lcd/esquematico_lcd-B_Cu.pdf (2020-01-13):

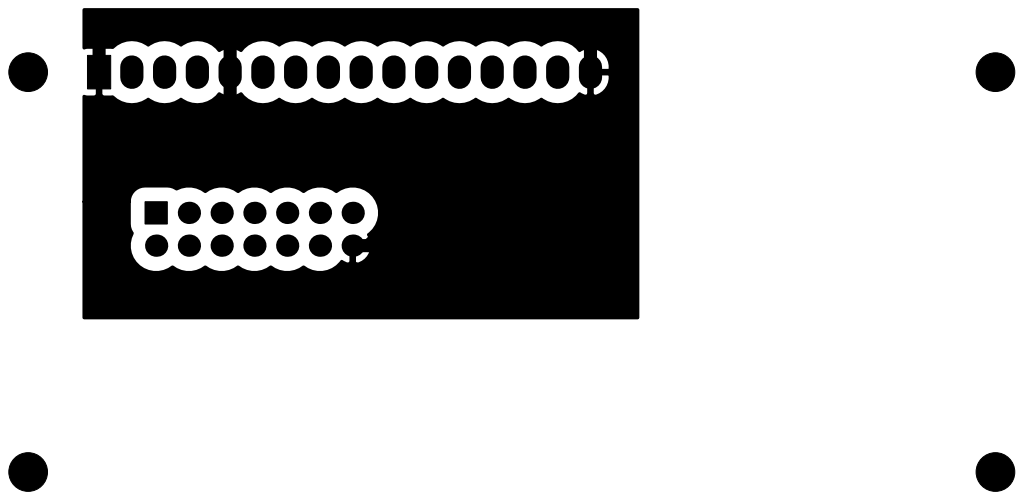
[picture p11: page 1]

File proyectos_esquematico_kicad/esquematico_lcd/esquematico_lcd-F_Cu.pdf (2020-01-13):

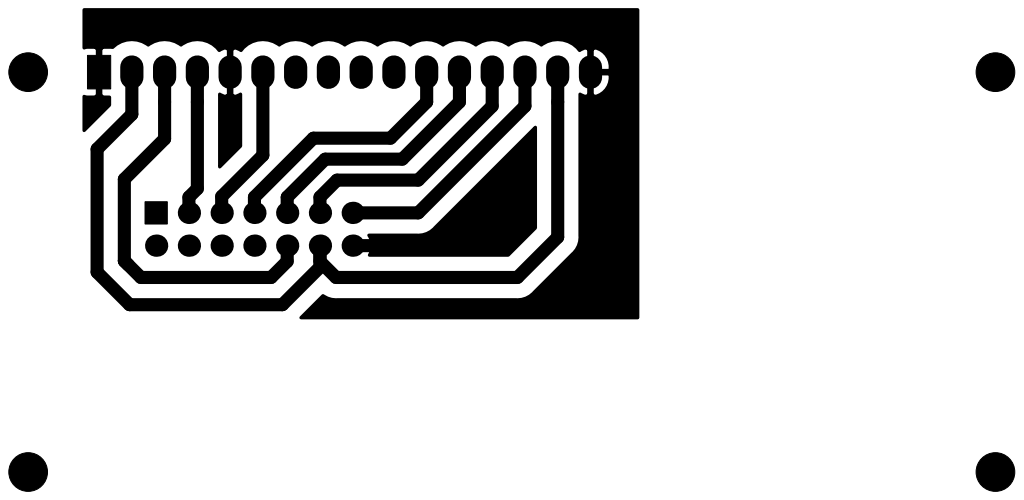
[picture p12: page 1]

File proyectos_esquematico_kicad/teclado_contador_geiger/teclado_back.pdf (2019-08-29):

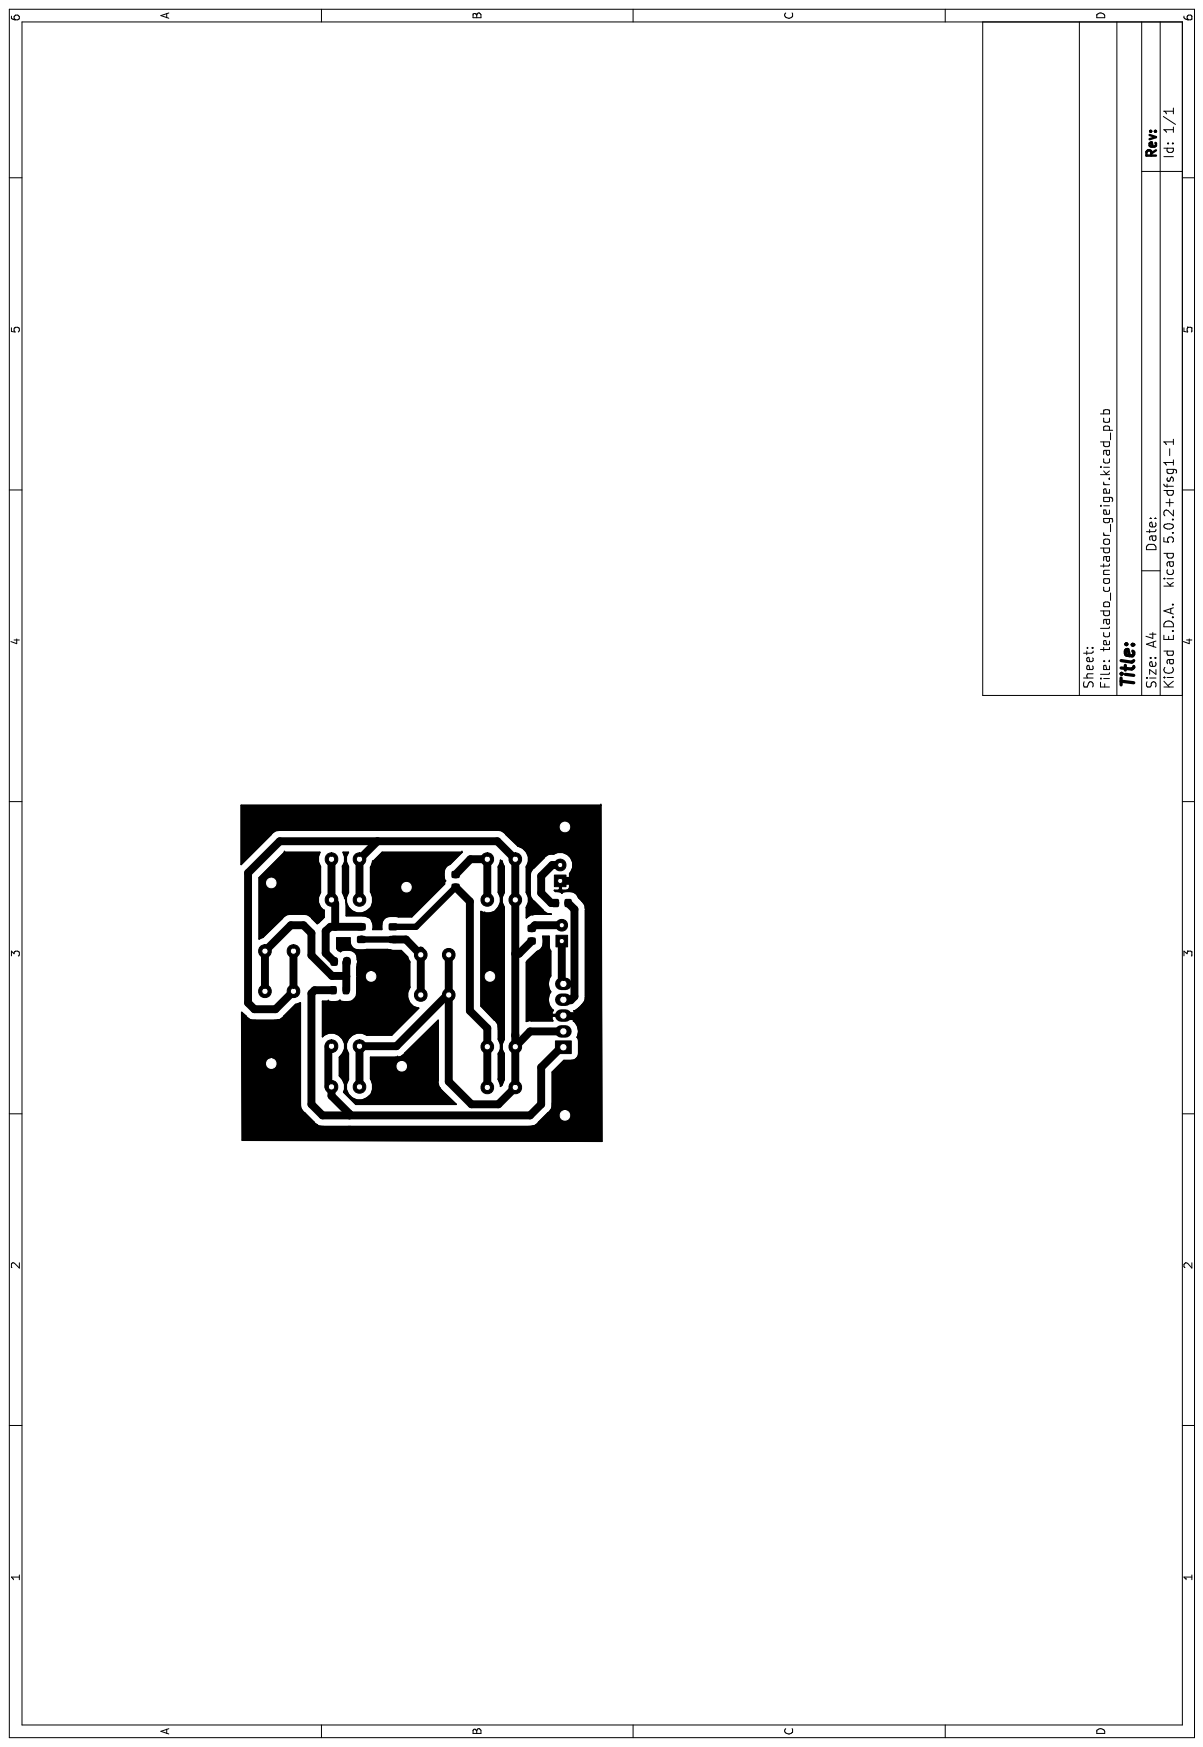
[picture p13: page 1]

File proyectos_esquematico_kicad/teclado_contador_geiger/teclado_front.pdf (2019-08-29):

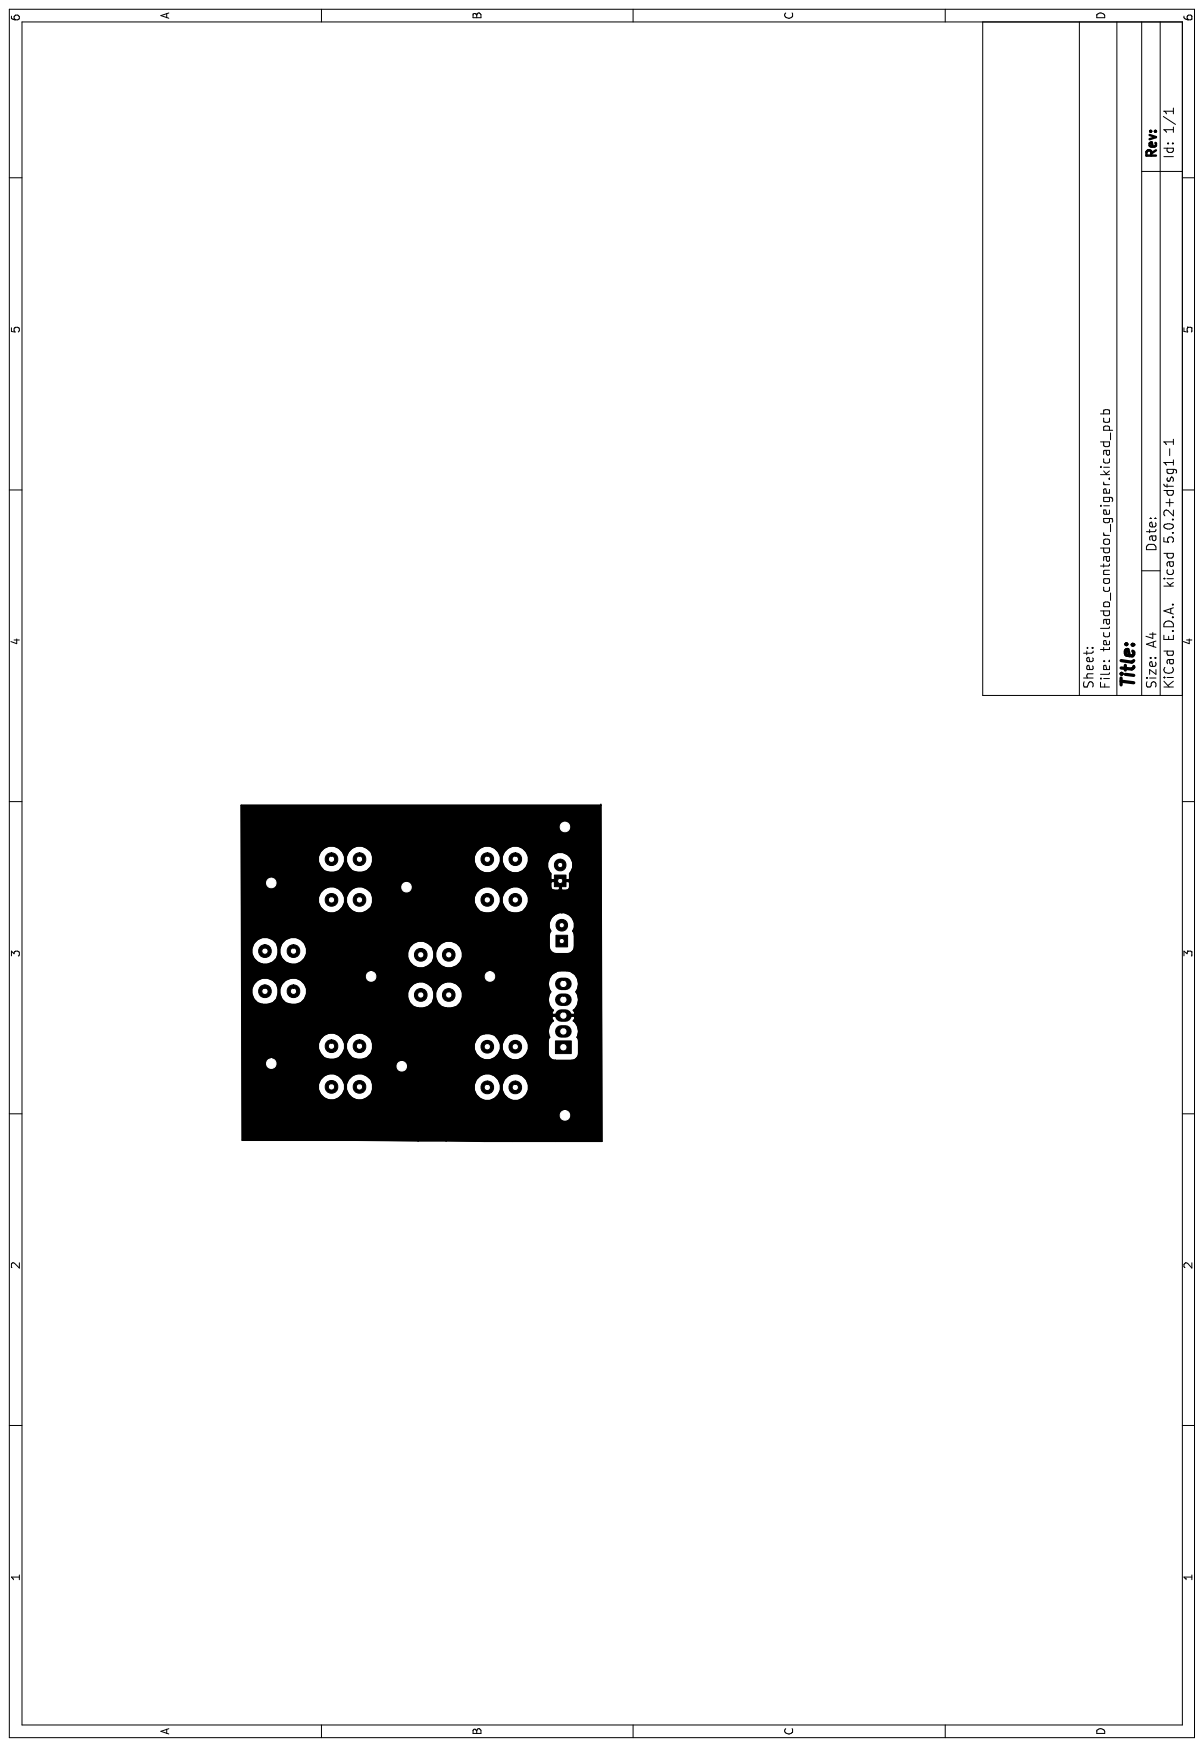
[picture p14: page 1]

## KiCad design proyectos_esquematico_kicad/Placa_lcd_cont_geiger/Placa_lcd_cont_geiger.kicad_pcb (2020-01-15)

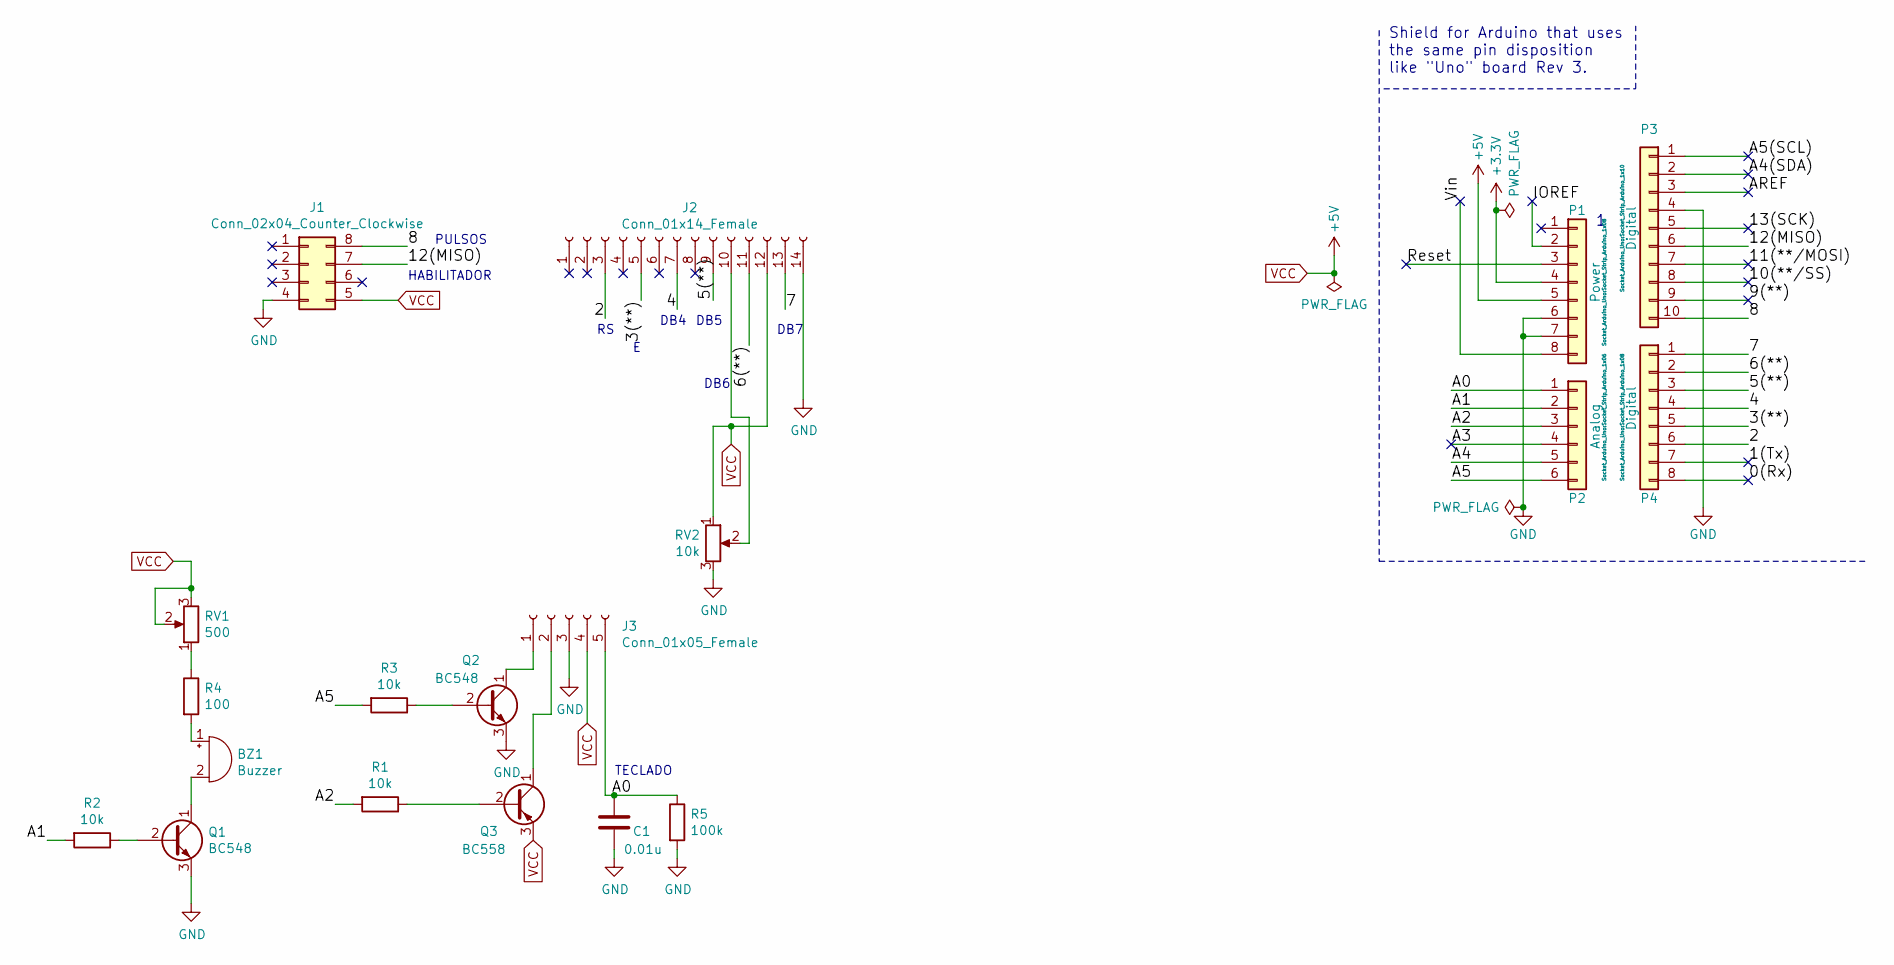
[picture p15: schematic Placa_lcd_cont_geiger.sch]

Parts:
BZ1: Buzzer; Buzzer_15x7.5RM7.6
C1: 0.01u; C_Axial_L5.1mm_D3.1mm_P7.50mm_Horizontal
J1: Conn_02x04_Counter_Clockwise; Molex_Mega-Fit_76825-0008_2x04_P5.70mm_Horizontal
J2: Conn_01x14_Female; IDC-Header_2x07_P2.54mm_Vertical
J3: Conn_01x05_Female; Molex_KK-6410-05_05x2.54mm_Straight
P1: Power; Socket_Strip_Arduino_1x08
P2: Analog; Socket_Strip_Arduino_1x06
P3: Digital; Socket_Strip_Arduino_1x10
P4: Digital; Socket_Strip_Arduino_1x08
Q1, Q2: BC548; TO-92_Inline_Wide
Q3: BC558; TO-92_Inline_Wide
R1, R2, R3: 10k; R_Axial_DIN0207_L6.3mm_D2.5mm_P10.16mm_Horizontal
R4: 100; R_Axial_DIN0207_L6.3mm_D2.5mm_P10.16mm_Horizontal
R5: 100k; R_Axial_DIN0207_L6.3mm_D2.5mm_P10.16mm_Horizontal
RV1: 500; Potentiometer_Bourns_3386F_Vertical
RV2: 10k; Potentiometer_Bourns_3386F_Vertical

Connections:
+3V3: P1.4
/0(Rx): P4.8
/1(Tx): P4.7
/2: J2.3, P4.6
/3(**): J2.5, P4.5
/4: J2.7, P4.4
/5(**): J2.9, P4.3
/6(**): J2.11, P4.2
/7: J2.13, P4.1
/8: J1.8, P3.10
/9(**): P3.9
/10(**/SS): P3.8
/11(**/MOSI): P3.7
/12(MISO): J1.7, P3.6
/13(SCK): P3.5
/A0: C1.1, J3.5, P2.1, R5.1
/A1: P2.2, R2.2
/A2: P2.3, R1.2
/A3: P2.4
/A4: P2.5
/A4(SDA): P3.2
/A5: P2.6, R3.2
/A5(SCL): P3.1
/AREF: P3.3
/IOREF: P1.2
/Reset: P1.3
/Vin: P1.8
GND: C1.2, J1.4, J2.14, J3.3, P1.6, P1.7, P3.4, Q1.3 (E), Q2.3 (E), R5.2, RV2.3
unnamed: BZ1.1 (-), R4.2
unnamed: BZ1.2 (+), Q1.1 (C)
unnamed: J2.10, RV2.2
unnamed: J3.1, Q2.1 (C)
unnamed: J3.2, Q3.1 (C)
unnamed: Q1.2 (B), R2.1
unnamed: Q2.2 (B), R3.1
unnamed: Q3.2 (B), R1.1
unnamed: R4.1, RV1.1
VCC: J1.5, J2.12, J3.4, P1.5, Q3.3 (E), RV1.2, RV1.3, RV2.1

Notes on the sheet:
Shield for Arduino that uses the same pin disposition like "Uno" board Rev 3.
DB7
DB6
DB5
DB4
HABILITADOR
PULSOS
TECLADO

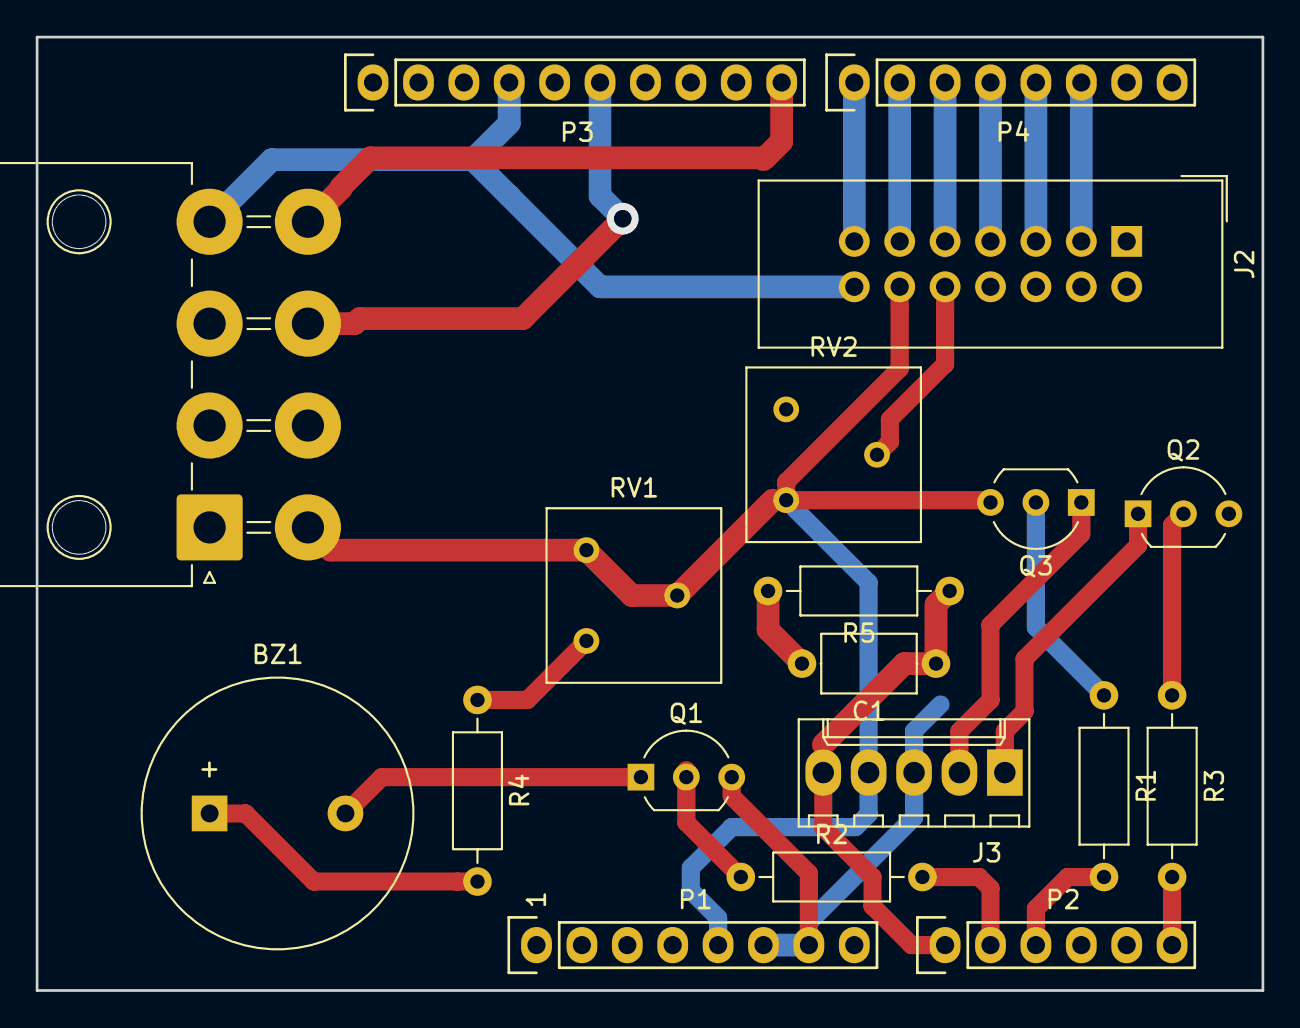
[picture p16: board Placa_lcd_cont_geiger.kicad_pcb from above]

Board: 2 copper layers, 68.6 x 53.3 mm, 19 parts (0 on the bottom side), 23 nets.

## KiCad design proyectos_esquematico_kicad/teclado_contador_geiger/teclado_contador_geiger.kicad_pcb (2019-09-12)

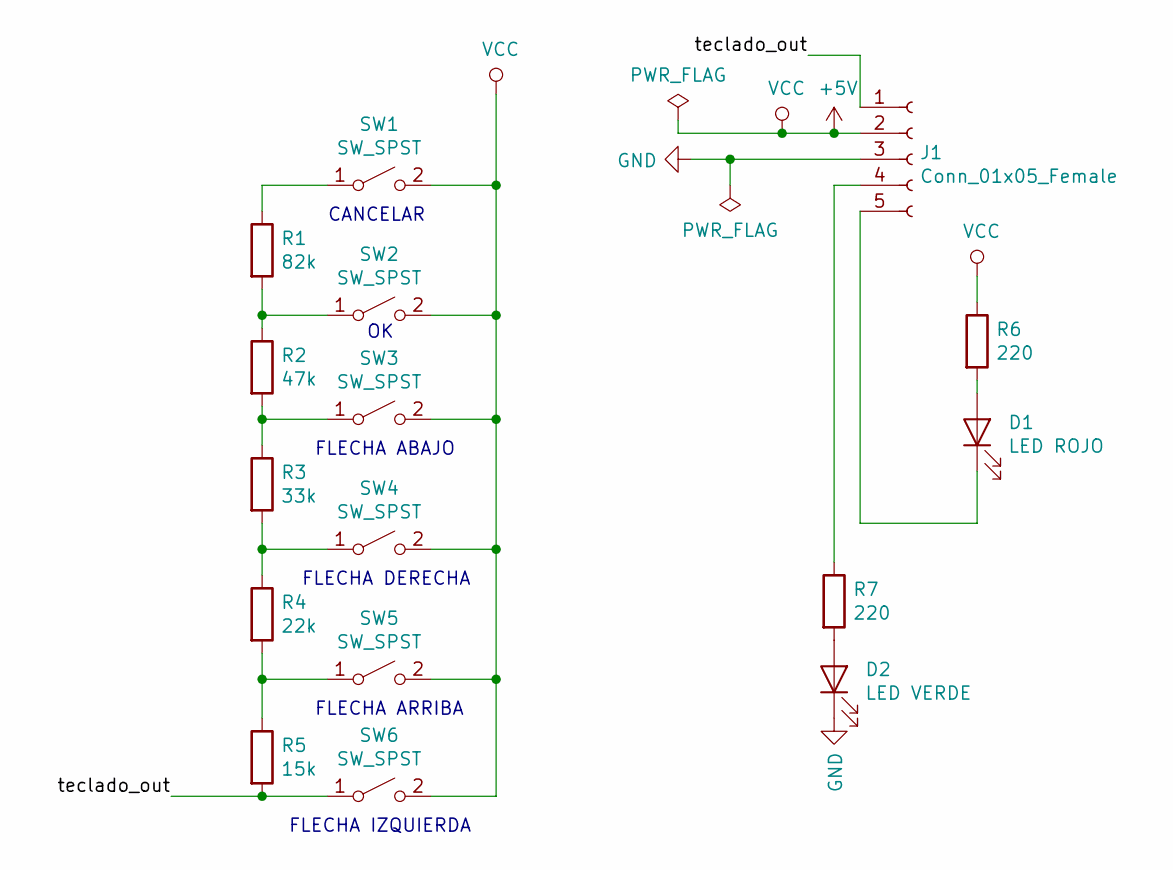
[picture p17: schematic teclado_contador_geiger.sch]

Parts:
D1: LED ROJO; LED_D5.0mm
D2: LED VERDE; LED_D5.0mm
J1: Conn_01x05_Female; Molex_KK-6410-05_05x2.54mm_Straight
R1: 82k; R_0805_2012Metric_Pad1.15x1.40mm_HandSolder
R2: 47k; R_0805_2012Metric_Pad1.15x1.40mm_HandSolder
R3: 33k; R_0805_2012Metric_Pad1.15x1.40mm_HandSolder
R4: 22k; R_0805_2012Metric_Pad1.15x1.40mm_HandSolder
R5: 15k; R_0805_2012Metric_Pad1.15x1.40mm_HandSolder
R6, R7: 220; R_0805_2012Metric_Pad1.15x1.40mm_HandSolder
SW1, SW2, SW3, SW4, SW5, SW6: SW_SPST; SW_PUSH_6mm

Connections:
+5V: J1.2, R6.1, SW1.2 (B), SW2.2 (B), SW3.2 (B), SW4.2 (B), SW5.2 (B), SW6.2 (B)
/teclado_out: J1.1, R5.2, SW6.1 (A)
GND: D2.1 (K), J1.3
unnamed: D1.1 (K), J1.5
unnamed: D1.2 (A), R6.2
unnamed: D2.2 (A), R7.2
unnamed: J1.4, R7.1
unnamed: R1.1, SW1.1 (A)
unnamed: R1.2, R2.1, SW2.1 (A)
unnamed: R2.2, R3.1, SW3.1 (A)
unnamed: R3.2, R4.1, SW4.1 (A)
unnamed: R4.2, R5.1, SW5.1 (A)

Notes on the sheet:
CANCELAR
FLECHA ABAJO
FLECHA DERECHA
FLECHA ARRIBA
FLECHA IZQUIERDA

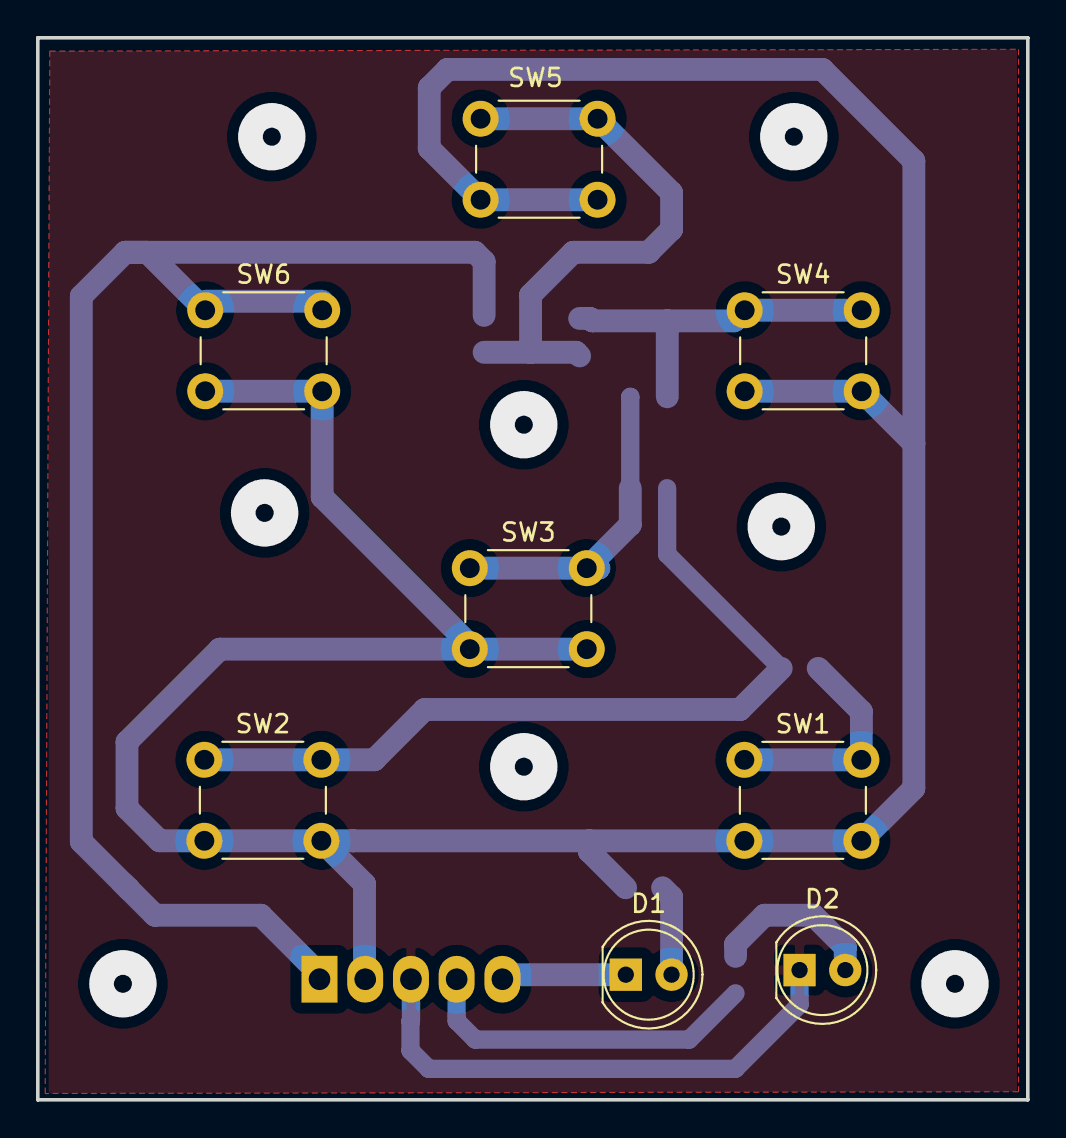
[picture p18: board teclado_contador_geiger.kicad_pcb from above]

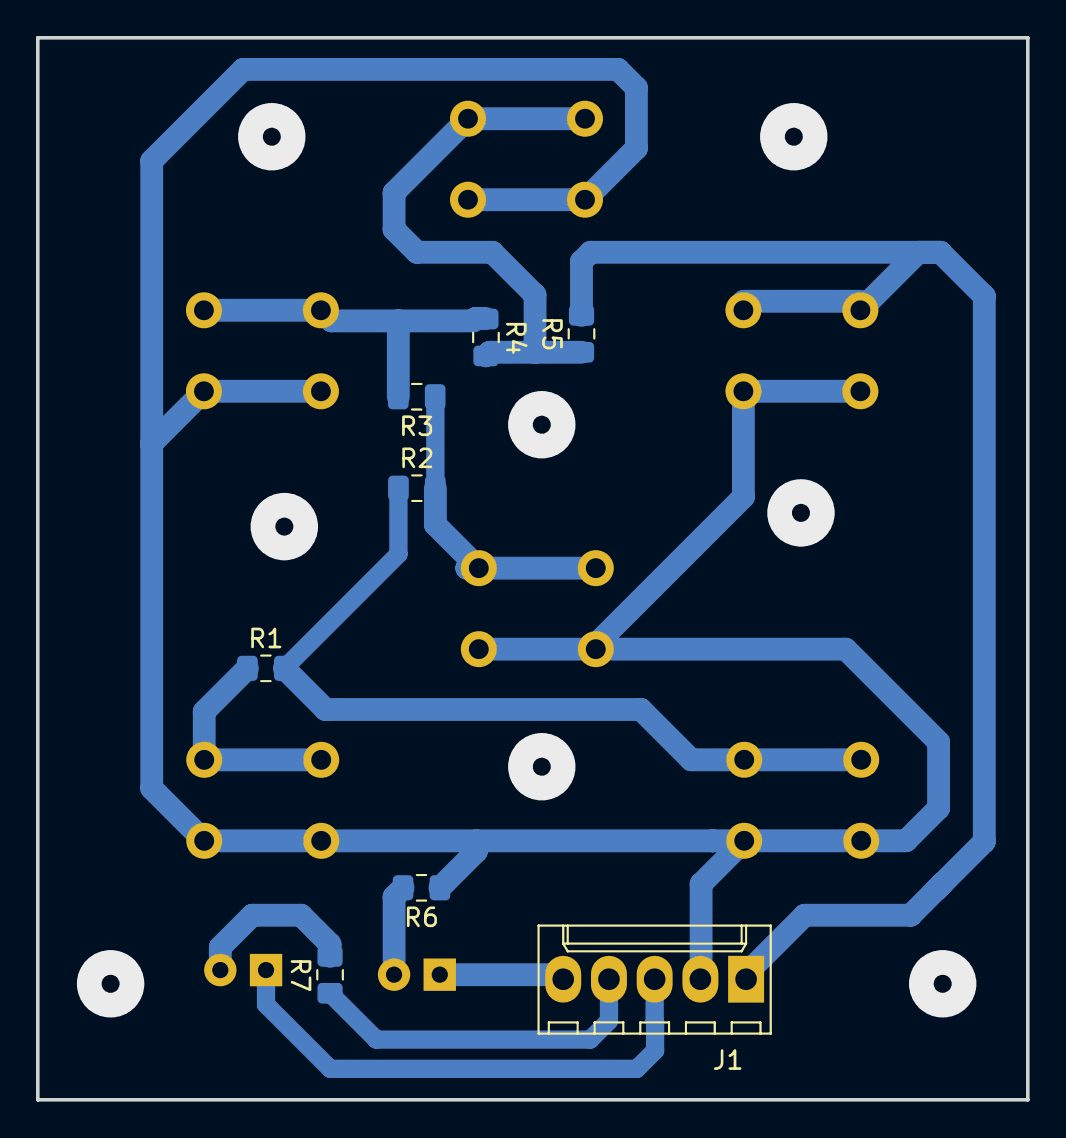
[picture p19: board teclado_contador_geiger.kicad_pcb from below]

Board: 2 copper layers, 55.0 x 59.0 mm, 16 parts (8 on the bottom side), 12 nets.

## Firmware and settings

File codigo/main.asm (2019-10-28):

; ==================================================================
; Archivo: main.asm
; ==================================================================

.include "m328pdef.inc"
.include "macros.inc"

; ===================================================================
; ========================= Variables globales ======================
; ===================================================================

; EVENTO: registro reservado para identificar eventos en el sistema que determinen
; acciones dentro de las maquinas de estados
; IMPORTANTE: la activacion de cada bit del registro simboliza la ocurrencia
; de un evento especifico. Si el bit esta en 0, entonces no ha ocurrido
; el evento
; Eventos asociados a cada bit:                                   
;    0  Timeout recibiendo una cadena                
;    1  Overflow de buffer recibiendo una cadena
;    2  Iniciar una lectura. Es equivalente a la recepcion de un comando READ? por UART
;    3  Abortar una lectura. Es equivalente a la recepcion de un comando ABORt por UART
;    4  Ha llegado un pulso
;	 5  Se estan enviando datos por UART
;    6  Se ha superado el umbral de pulsos configurado
;    7  Se ha presionado una tecla
.def EVENTO = R25

; EVENTO2: registro en RAM reservado para identificar eventos en el sistema que determinen
; acciones dentro de las maquinas de estados
; IMPORTANTE: la activacion de cada bit del registro simboliza la ocurrencia
; de un evento especifico. Si el bit esta en 0, entonces no ha ocurrido
; el evento
; Eventos asociados a cada bit:                                   
;    0  Se ha recibido un caracter
;    1  Se ha terminado de recibir una cadena
;    2  El sistema se encuentra ocupado durante un pedido externo
;	 3  Indica la disminucion del registro que almacena el multiplicador de ventana
;    4  Se ha configurado el dispositivo para que mida ventanas infinitas (es decir, que nunca pare de medir)       
.dseg
EVENTO2: .BYTE 1
.cseg

; Constantes para identificar cada bit de EVENTO
.equ TIMEOUT_UART = 0
.equ OV_BUFFER_RX_UART = 1
.equ COMENZAR_MEDICION = 2
.equ DETENER_MEDICION = 3
.equ PULSO_RECIBIDO = 4
.equ ENVIANDO_DATOS_UART = 5
.equ UMBRAL_SUPERADO = 6
.equ TECLA_PRESIONADA = 7

; Constantes para identificar cada bit de EVENTO2
.equ BIT_CARACTER_RECIBIDO = 0
.equ BIT_FIN_CADENA = 1
.equ SISTEMA_OCUPADO = 2
.equ BIT_MUL_VENTANA_DEC = 3
.equ BIT_VENTANAS_INF = 4

; ESTADO: variable para identificar el estado de las maquinas de estados
; IMPORTANTE: cada bit, al estar activado, indica que la maquina debe estar
; en un estado especifico. Dos bits no pueden estar activos al mismo tiempo.
;
; Estados asociados a cada bit:
; --> De 0 a 3 inclusive con estados de la maquina de estados de la UART
;    0  Estado oscioso de la UART   
;    1  Recibiendo una cadena
;    2  Intepretando una cadena
;    3  Se produjo un error en la recepcion de datos por UART
; --> De 4 a 7 inclusive son estados de la maquina de estados para realizar mediciones
;    4  Estado oscioso del sistema de mediciones
;	 5  ACTUALMENTE SIN USO
;    6  Midiendo devolviendo los tiempos de llegada de cada pulso
;	 7  Midiendo sin devolver los tiempos de llegada de cada pulso
.def ESTADO = R24

; Constantes para identificar cada bit de ESTADO
.equ EST_OSCIOSO_UART = 0
.equ EST_RECIBIENDO_CADENA = 1
.equ EST_INTERPRETANDO_CADENA = 2
.equ EST_ERROR_UART = 3
.equ EST_OSCIOSO_MEDICION = 4
.equ EST_MEDIR_DEVOLVER_TIEMPOS = 6
.equ EST_MEDIR_DEVOLVER_TOTAL = 7


; MUL_DE_VENTANA: multiplicador que permite ampliar el registro OCR1A (registro
; comparador del timer1)
.def MUL_DE_VENTANA = R15

; ===================================================================
; ========================= Interrupciones ==========================
; ===================================================================

.org 0
	JMP INICIO

; Interrupcion de buffer de RX lleno
.org URXCaddr
	JMP USART_RX

; Interrupcion de buffer de TX vacio
.org UDREaddr
	JMP USART_UDRE

; Interrupcion de overflow del timer0
.org OVF0addr
	JMP OVERFLOW_TIMER0

;Interrupción por overflow del timer 2
.org OVF2addr
	JMP LCD_INTERRUPCION_OVERFLOW			

;Interrupción por detección de flanco de en el ICP1	
.org ICP1addr	
	JMP INTERRUPCION_PULSO_DETECTADO

;Interrupción por comparación del TIMER 1
.org OC1Aaddr
	JMP INTERRUPCION_FIN_VENTANA

; Interrupcion del comparador analogico
.org ACIaddr
	JMP INTERRUPCION_COMPARADOR

; Interrupcion de conversion por ADC completa
.org ADCCaddr
		RJMP ADC_ISR

; ===================================================================
; ========================= Codigo principal ========================
; ===================================================================


.org INT_VECTORS_SIZE

; ========================== Dependencias ========================== 
.include "Uso_general.asm"
.include "configuracion.asm"
.include "eeprom.asm"
.include "perifericos/adc.asm"
.include "perifericos/teclado.asm"
.include "perifericos/comparador.asm"
.include "perifericos/LCD.asm"
.include "com_serie/uart.asm"
.include "com_serie/scpi.asm"
.include "timers/TIMER_0.asm"
.include "timers/TIMER_2.asm"
.include "timers/TIMER_1.asm"
.include "mediciones/Mediciones.asm"
.include "mediciones/pulsos_registro_desplazamiento.asm"
.include "maquinas_de_estado/maquina_estados_uart.asm"
.include "maquinas_de_estado/maquina_estados_mediciones.asm"
.include "maquinas_de_estado/maquina_estados_LCD.asm"
; ========================== Fin dependencias ======================

INICIO:

	; No hay eventos por procesar al comenzar el programa
	CLR EVENTO
	STS EVENTO2, EVENTO

	; Las maquinas de estado comienzan en estado oscioso
	CLR ESTADO
	SBR ESTADO, (1<<EST_OSCIOSO_MEDICION)
	SBR ESTADO, (1<<EST_OSCIOSO_UART)

	; Inicializar el stack
	LDI R16, LOW(RAMEND)
	OUT SPL, R16
	LDI R16, HIGH(RAMEND)
	OUT SPH, R16

	; Borrar el registro de motivos del timer0
	LDS R16, MOTIVO_TIMER0
	CLR R16
	STS MOTIVO_TIMER0, R16

	; Limpiar el contenido del registro de desplazamiento para enviar los tiempos de los pulsos
	CLR CANT_CARACTERES_GUARDADOS

	; Cargar configuracion del dispositivo por default
	CALL CARGAR_CONFIGURACION_EEPROM

	; Configurar puertos del LCD
	CALL CONFIGURAR_PUERTOS_LCD

	; ====== Configurar timers y com. serie ===========
	CLI
	
	; Configurar el comparador
	CALL CONF_COMPARADOR

	; Configurar el ADC
	CALL CONF_ADC
	
	; Configurar UART
	CALL INICIALIZAR_UART
	CALL ACTIVAR_TX_RX
	CALL ACTIVAR_INT_RX
	
	; Activar las interrupcion por overflow del TIMER 0 
	; para detectar timeouts en la comunicacion serie
	CALL ACTIVAR_ISR_TIMER0_OV	
	
	;Inicializar el TIMER 2 para las interrupciones del LCD
	CALL INIT_TIMER_2
	
	;Inicializar el TIMER 1 para captar los pulsos de las mediciones
	CALL INIT_TIMER_1
	SEI	

	; ====== Fin configurar timers y com. serie ===========
	
	; Inicializar la pantalla LCD
	CALL INIT_LCD

	; Enviar mensaje de bienvenida por UART
	LDI R18, LOW(MENSAJE_UART_INICIAL)
	LDI R19, HIGH(MENSAJE_UART_INICIAL)
	CALL CARGAR_BUFFER
	CALL ACTIVAR_INT_TX_UDRE0	

	; Configurar pantalla LCD para comenzar en el menú principal:
	; Se habilita la escritura en ambos renglones del LCD, y se entra en el menú principal,
	; mostrando en el segundo renglón la opción de entrar al menú de umbral.
	LDI ESTADOS_LCD, VOLVER_MENU_PRINCIPAL


	; ====== Pines ===========	
	; Configurar pines asociados a indicadores luminosos o sonoros como salidas
	SBI DDRC, PIN_PORTC_LED_SUP_UMBRAL
	SBI DDRC, PIN_PORTC_LED_INF_UMBRAL
	SBI DDRC, PIN_PORTC_BUZZER

	CBI PORTC, PIN_PORTC_LED_SUP_UMBRAL
	SBI PORTC, PIN_PORTC_LED_INF_UMBRAL
	CBI PORTC, PIN_PORTC_BUZZER

	
BUCLE_PRINCIPAL:
	
	; =================== CHEQUEAR TUBO ====================================
	; Chequear si la configuracion almacenada indica que el tubo debe estar activado.
	; De ser asi, activarlo. Sino, desactivarlo. 
	CALL VERIFICAR_APAGADO_TUBO
	; =================== FIN CHEQUEAR TUBO ================================


	CLR R16

	; =============================== ADC ==================================
	; Si se ha presionado una tecla, entonces identificarla

	SBRC EVENTO, TECLA_PRESIONADA
	CALL ADC_LEER_TECLA
	; LA TECLA PRESIONADA QUEDA ALMACENADA EN LOS REGISTROS R18 Y R19 PERO SOLO
	; DE FORMA TEMPORAL. LA MAQUINA DE ESTADOS DEL LCD DEBE SER COLOCADA INMEDIATAMENTE
	; DEBAJO DE ESTE CODIGO PORQUE SINO OTRA FUNCION PODRIA 
	; BORRAR LOS VALORES DE R18 Y R19
	; =============================== FIN ADC ==============================


	; =======================================================================
	; ====================== MAQUINAS DE ESTADO =============================
	; =======================================================================

	
	; ================== Maquina de estados del LDC =========================
	; Maquina de estados dedicada a mostrar por pantalla los menús correspondientes
	; al usuario

	CPI ESTADOS_LCD, MIDIENDO_LCD
	BREQ _SKIPEAR_MAQUINA_ESTADOS_LCD

	CALL MAQUINA_ESTADOS_LCD

_SKIPEAR_MAQUINA_ESTADOS_LCD:

	; ================== Maquina de estados de las mediciones ===============
	; Maquina de estados dedicada a la gestion de las mediciones
	CALL MAQUINA_ESTADOS_MEDICIONES

	; ================== Maquina de estados de UART =========================
	; Maquina de estados dedicada a la recepcion o envio de una cadena por UART
	 CALL MAQUINA_ESTADOS_UART


	; =======================================================================
	; ======================= FIN MAQUINAS DE ESTADO =======================	
	; =======================================================================

	RJMP BUCLE_PRINCIPAL
	RJMP END

END: RJMP END

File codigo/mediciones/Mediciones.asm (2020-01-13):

; ==================================================================
; Archivo: Mediciones.asm
; Descripcion: biblioteca con funciones relacionadas 
; con las mediciones a realizar.
; ==================================================================

; ===================================================================
; ========================= Variables ===============================
; ===================================================================
.dseg

MUL_DE_VENTANA_RAM: .byte 1				;Memoria para guardar el mul de ventana en ram

CONTADOR_DE_PULSOS_RAM: .byte 3			;Se irán acumulando el total de pulsos medidos en cada ventana: [nibble bajo];[nibble medio];[nibble alto]

.cseg
; UMBRAL_A_SUPERAR: se guardará la configuración del umbral a superar.
.DEF UMBRAL_A_SUPERAR = R21

; CONTADOR_DE_PULSOS: se lleva la cuenta de la cantidad de pulsos medidos.
.DEF CONTADOR_DE_PULSOS = R23

; VENTANA_DE_TIEMPO: se define la duracion de la ventana de tiempo de las mediciones
; 0 = 1ms, 1 = 10ms, 2 = 100ms, 3 = 1s
.DEF VENTANA_DE_TIEMPO = R26


.DEF VENTANAS_A_MEDIR_LOW = R7
.DEF VENTANAS_A_MEDIR_MID = R5
.DEF VENTANAS_A_MEDIR_HIGH = R13

; ===================================================================
; ========================= Constantes ==============================
; ===================================================================
.cseg

; Si se utiliza una ventana 100 ms, se cuenta 25000 con el timer1, 
; con un prescaler de clk/64 = 250khz.
.EQU VENTANA_LOW = 0xA8	
.EQU VENTANA_HIGH = 0x61

; CANTIDAD DE VECES QUE SE VA A REALIZAR EL REINICIO DEL CLOCK, 
; PARA SEGUIR MIDIENDO: EN ESTE CASO, CON UN
; PRESCALER DE CLK/64, CONTAR 50 VECES ES 5 segundos.
.EQU DURACION_TOTAL = 100

;CONFIGURACIÓN DEL UMBRAL
.EQU PIN_PORTC_LED_SUP_UMBRAL = 5
.EQU PIN_PORTC_BUZZER = 1
.EQU PIN_PORTC_LED_INF_UMBRAL = 2

; PUERTO DE ACTIVACION/DESACTIVACION DEL CONTADOR
.EQU PUERTO_ACTIVAR_CONTADOR = 4

; CONFIGURACIÓN DE LA DURACIÓN DE LA VENTANA
.EQU VENTANA_1ms = 0					
.EQU VENTANA_10ms = 1
.EQU VENTANA_100ms = 2
.EQU VENTANA_1000ms = 3

; VALORES DEL COMPARADOR DEL TIMER, DEPENDIENDO DE LA VENTANA SELECCIONADA

.EQU VENTANA_HIGH_1ms = 0x00			;0x00FA = 250
.EQU VENTANA_LOW_1ms = 0xFA

.EQU VENTANA_HIGH_10ms = 0x09			;0x09C4 = 2500
.EQU VENTANA_LOW_10ms = 0xC4

.EQU VENTANA_HIGH_100ms = 0x61			;0x61A8 = 25000
.EQU VENTANA_LOW_100ms = 0xA8

.EQU VENTANA_HIGH_1000ms = 0xC3			;0xC350 = 50000
.EQU VENTANA_LOW_1000ms = 0x50

; REPETIDORES DE OVERFLOW DEL TIMER PARA COMPLETAR UNA VENTANA
.EQU REPETIDOR_OVERFLOW_TIMER_1ms = 0x01
.EQU REPETIDOR_OVERFLOW_TIMER_10ms = 0x01
.EQU REPETIDOR_OVERFLOW_TIMER_100ms = 0x01
.EQU REPETIDOR_OVERFLOW_TIMER_1000ms = 0x05


; ===================================================================
; ========================= Funciones ===============================
; ===================================================================

; Descripcion: configura la ventana de tiempo que se utilizará para las mediciones. 
;              Se utiliza el registro VENTANA_DE_TIEMPO para saber qué ventana se emplea.
; Recibe: -
; Devuelve: -

; SETEO DE LA CONFIGURACIÓN DE LA VENTANA DE TIEMPO: 
; --> Si VENTANA_DE_TIEMPO = 0, entonces 1ms; 
; --> Si VENTANA_DE_TIEMPO = 1, entonces 10ms; 
; --> Si VENTANA_DE_TIEMPO = 2, entonces 100ms;
; -- >Si VENTANA_DE_TIEMPO = 3, entonces 1000ms
; DEPENDIENDO DE CUAL ES EL VALOR DE VENTANA_DE_TIEMPO, 
; SE HACE UN SALTO PARA HACER LA CONFIGURACIÓN ADECUADA

CONFIG_VENTANA_DE_TIEMPO:
	PUSH R19
	PUSH R20
	PUSH R21

	CPI VENTANA_DE_TIEMPO, VENTANA_1ms
	BREQ CONFIG_1ms

	CPI VENTANA_DE_TIEMPO, VENTANA_10ms
	BREQ CONFIG_10ms

	CPI VENTANA_DE_TIEMPO, VENTANA_100ms
	BREQ CONFIG_100ms

	CPI VENTANA_DE_TIEMPO, VENTANA_1000ms
	BREQ CONFIG_1000ms
	
	CONFIG_1ms:
		LDI R20, VENTANA_HIGH_1ms					;ANCHO DE VENTANA (NIBBLE ALTO) 1ms
		LDI R21, VENTANA_LOW_1ms					;ANCHO DE VENTANA (NIBBLE BAJO) 1ms
		LDI R19, REPETIDOR_OVERFLOW_TIMER_1ms		;CANTIDAD DE VECES QUE SE DEBE HACER OVERFLOW AL TIMER 1 PARA QUE SE CUMPLA UNA VENTANA
		RJMP CARGAR_VENTANA							;UNA VEZ CONFIGURADO EL VALOR SE CARGA

	CONFIG_10ms:
		LDI R20, VENTANA_HIGH_10ms
		LDI R21, VENTANA_LOW_10ms
		LDI R19, REPETIDOR_OVERFLOW_TIMER_10ms
		RJMP CARGAR_VENTANA

	CONFIG_100ms:
		LDI R20, VENTANA_HIGH_100ms
		LDI R21, VENTANA_LOW_100ms
		LDI R19, REPETIDOR_OVERFLOW_TIMER_100ms
		RJMP CARGAR_VENTANA

	CONFIG_1000ms:
		LDI R20, VENTANA_HIGH_1000ms
		LDI R21, VENTANA_LOW_1000ms
		LDI R19, REPETIDOR_OVERFLOW_TIMER_1000ms
		RJMP CARGAR_VENTANA

	CARGAR_VENTANA:
		MOV MUL_DE_VENTANA, R19					;SE CARGA EL MULTIPLICADOR DE VENTANA
		STS OCR1AH, R20							;SE CARGA EL VALOR DE COMPARACIÓN DEL TIMER, EN OCR1AH|OCR1AL
		STS OCR1AL, R21							;AUTOMATICAMENTE CUANDO SE CARGA EL LOW NIBBLE, SE CARGAN AMBOS AL MISMO TIEMPO
		RJMP FIN_CONFIG_VENTANA					;SE TERMINÓ DE CONFIGURAR LA VENTANA, SE SALE DE LA FUNCIÓN

	FIN_CONFIG_VENTANA:
		POP R21
		POP R20
		POP R19
		RET

; ==================================================================
; Descripcion: carga la configuración de la cantidad de veces que se va a repetir la ventana.
; Recibe: VENTANAS_A_MEDIR_RAM
; Devuelve: VENTANAS_A_MEDIR_HIGH, VENTANAS_A_MEDIR_MID, VENTANAS_A_MEDIR_LOW
CONFIG_REPETIR_VENTANAS:

	LDS VENTANAS_A_MEDIR_HIGH, VENTANAS_A_MEDIR_RAM+2		;Se carga el nibble bajo de la configuración del usuario, en un registro VENTANAS_A_MEDIR_LOW
	MOV VENTANAS_A_MEDIR_LOW, VENTANAS_A_MEDIR_HIGH
	LDS VENTANAS_A_MEDIR_HIGH, VENTANAS_A_MEDIR_RAM+1		
	MOV VENTANAS_A_MEDIR_MID, VENTANAS_A_MEDIR_HIGH			;Se carga el nibble intermedio de la configuración del usuario, en un registro VENTANAS_A_MEDIR MID
	LDS VENTANAS_A_MEDIR_HIGH, VENTANAS_A_MEDIR_RAM			;Se carga el nibble alto de la configuración del usuario, en un registro VENTANAS_A_MEDIR HIGH

	RET


; ==================================================================
; Descripcion: inicializa el registro CONTADOR_DE_PULSOS, 
; donde se cuenta la cantidad de pulsos totales medidos.
; Recibe: CONTADOR_DE_PULSOS (R23)
; Devuelve: CONTADOR_DE_PULSOS (R23)
CONFIG_CONTADOR_DE_PULSOS:
	LDI CONTADOR_DE_PULSOS, 0x00
	STS CONTADOR_DE_PULSOS_RAM, CONTADOR_DE_PULSOS
	LDI CONTADOR_DE_PULSOS, 0x00
	STS CONTADOR_DE_PULSOS_RAM+1, CONTADOR_DE_PULSOS
	LDI CONTADOR_DE_PULSOS, 0x00
	STS CONTADOR_DE_PULSOS_RAM+2, CONTADOR_DE_PULSOS

	RET
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

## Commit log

2019-02-22 Primer commit despues del clone del repo de labo de micro
    [Arduino_UNO.sch, Contador_Geiger.kicad_pcb, Contador_Geiger.sch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]
2019-03-11 Mejora en la documentacion y cambios menores
2019-04-29 Agregado del CAD de la caja
    [caja_alta_tension.scad, prueba_1_caja.stl]
2019-08-16 Subo los archivos del PCB del LCD y teclado
    [Placa_LCD_cont-geiger.kicad_pcb, Placa_LCD_cont-geiger.sch]
2019-08-16 Esquemático de la placa del LCD en KiCad v5
    [Placa_LCD_cont-geiger.kicad_pcb, Placa_LCD_cont-geiger.sch, Placa_lcd_cont_geiger.kicad_pcb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]
2019-08-17 Actualización del PCB del shield
2019-08-18 Agregado del PCB del teclado
    [Arduino_UNO.sch, Contador_Geiger.kicad_pcb, Contador_Geiger.sch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]
2019-08-18 Agregado del PCB del teclado(2)
    [Placa_lcd_cont_geiger.kicad_pcb, Placa_lcd_cont_geiger.sch, teclado_contador_geiger.kicad_pcb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]
2019-08-21 Cambios varios en la documentación
    [caja_alta_tension.scad, prueba_1_caja.stl]
2019-08-23 Agregado de LED verde a la placa del teclado e incremento de las dimensiones de esta última incluyendo una mayor separación entre los botones
    [Placa_lcd_cont_geiger.kicad_pcb, Placa_lcd_cont_geiger.sch, teclado_contador_geiger.kicad_pcb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]
2019-08-26 Agrega PCB del teclado
    [Placa_lcd_cont_geiger.kicad_pcb, Placa_lcd_cont_geiger.sch, teclado_contador_geiger.kicad_pcb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]
2019-08-29 Se modificó distancia entre dos resistencias de la placa teclado
    [Placa_lcd_cont_geiger.kicad_pcb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]
2019-09-12 Modificaciones en el PCB para poder mardarlo a hacer al LCI. Agregado del esquematico del Arduino UNO R3 actualizado a la carpeta 'doc'
    [Arduino_UNO.sch, Contador_Geiger.kicad_pcb, Contador_Geiger.sch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]
2019-09-12 Actualizacion de los gerbers y de los drills (cambios necesarios para poder mandar a hacer las placas al LCI)
    [Placa_lcd_cont_geiger-B.Cu.gbr, Placa_lcd_cont_geiger-B.SilkS.gbr, Placa_lcd_cont_geiger-B_Cu.gbr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]
2019-09-23 Se sube el archivo de la caja completo
    [caja_alta_tension.scad, prueba_1_caja.stl]
2019-10-15 Empieza PCB del LCD
    [esquematico_lcd.kicad_pcb, esquematico_lcd.sch]
2019-10-24 Cambios en el código para integrar el encendido y apagado del led verde
2019-10-28 Agregado de la funcionalidad para medir infinitas ventanas y corrección de bugs
    [configuracion.asm, main.asm, maquina_estados_mediciones.asm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]
2019-12-23 Se agrega routeo LCD PCB
    [esquematico_lcd.kicad_pcb]
2020-01-10 Cambios menores al PCB del LCD
    [esquematico_lcd.kicad_pcb]
2020-01-13 Cambio del pin del buzzer
    [Mediciones.asm]
2020-01-15 Cambios menores en el shield para adaptarlo a los cambios hechos sobre el prototipo
    [Placa_lcd_cont_geiger.kicad_pcb, Placa_lcd_cont_geiger.sch]
2020-01-15 Cambios menores en el shield para adaptarlo a los cambios hechos sobre el prototipo(1)
